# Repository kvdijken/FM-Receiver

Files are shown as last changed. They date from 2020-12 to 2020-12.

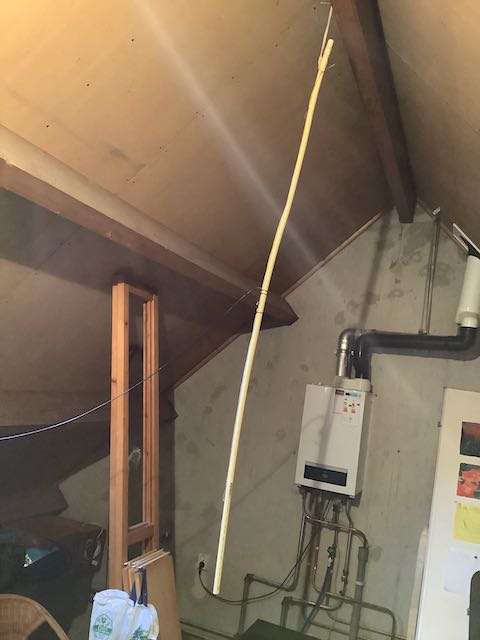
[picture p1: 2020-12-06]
photos/dipole antenna.jpeg

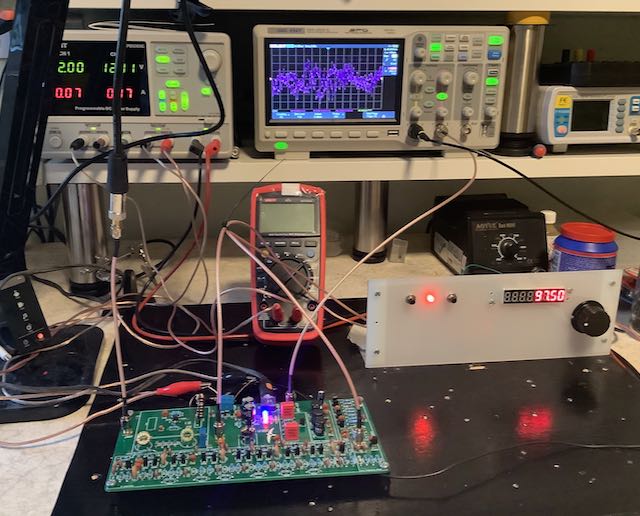
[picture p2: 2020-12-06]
photos/receiver.jpeg

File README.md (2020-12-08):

# FM Receiver

In this project you will find my home built FM receiver. The goal is to create a receiver with discrete components only, no integrated circuits. It delivers line level audio. It only needs an additional audio amplifier to be able to hear your favorite radio station from the speakers.

Performance is very good. I receive all FM radio stations with great clarity. Its sensitivity is 11𝜇V.

It lets you dial into preprogrammed radio stations, or to select frequencies yourself. Also you can change some internal receiver parameters such as intermediate frequencies and lowside/highside injection. 

The user interface runs on an Arduino Nano 328P. The receiver itself is built off discrete parts, no integrated parts are used.

In this project you will find
* Arduino source code of the digital section (in folder 'firmware/FM Radio 5.8')
* Kicad project with the schematic and pcb layout of the analog section (in folder 'hardware')
* documentation (in folder 'documentation')
* a Python project to model differential pair amplifiers (in folder 'IF Amplifier')
* some photos of my implementation
* measurements I have done on this receiver (in folder 'measurements').

In this project you will not find the schematic for the digital section yet. I will still have to create this schematic. The digital section is not complicated however. It consists of an Arduino Nano, three pushbuttons, one LED, 1 rotary encoder, one display and one Adafruit Si5351 breakout board. From the Arduino sourcecode you should be able to discover the wiring. The Si5351 delivers the two local oscillator frequencies which are needed for the receiver.

Keep in mind that the schematic, and the pcb which is derived from the schematic contain an serious error. I kept this error in the schematic, to keep the schematic and pcb design in sync. The error is described in the documentation. Also is described how to work around the error, which is quite simple. You can still use the pcb design, even with this bug. In the next version of this receiver this error will be solved.

In the next few weeks, months, my main focus will be on measurements on the receiver. I will try to characterise the receiver as well as possible. From there the receiver can be improved.

On Youtube you can find a demonstration of this receiver: https://youtu.be/TlIiLwKdwg0

Current version is 1.0

Feel free to ask/contribute.

> Written with [StackEdit](https://stackedit.io/).

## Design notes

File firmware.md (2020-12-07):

#FM Radio 5.8

To compile this Arduino sketch you will need the following libraries on your machine:

LedControl.h
from https://github.com/wayoda/LedControl or from the Library Manager in the Arduino IDE

si5351.h
from https://github.com/etherkit/Si5351Arduino or from the Library Manager in the Arduino IDE

Encoder.h
from https://github.com/PaulStoffregen/Encoder

Bounce2.h
can be installed from the  Library Manager in the Arduino IDE

> Written with [StackEdit](https://stackedit.io/).

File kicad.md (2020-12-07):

# Kicad project

For the Kicad project of th FM Receiver you will need the following:

* Digikey's Kicad symbol library, available from https://github.com/Digi-Key/digikey-kicad-library
* kvd footprint library, available in the `FM Receiver/kicad/kvd.pretty` folder

> Written with [StackEdit](https://stackedit.io/).

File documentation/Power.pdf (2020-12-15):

# Power

Measurements taken on version 1.0 of the receiver.

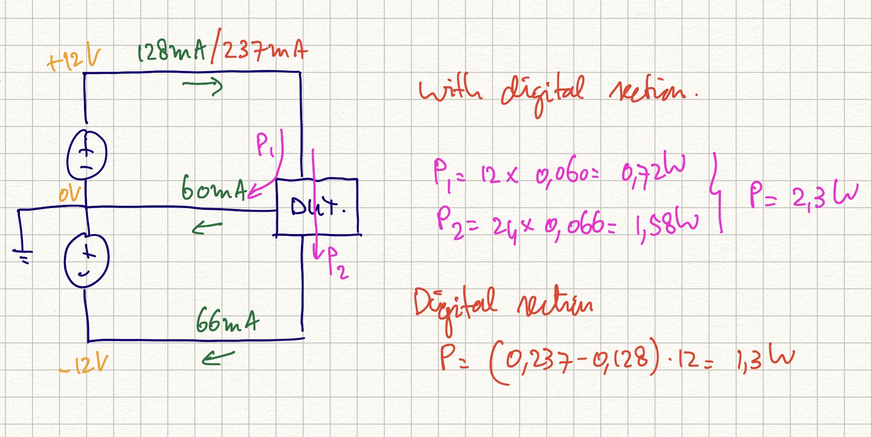
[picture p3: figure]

Power requirements:
- analog section 2.3 Watt
- digital section 1.3 Watt
| T (℃) | V (V) | R (Ω) | P (W)
R507 | 50 | 16.6 | 1100 | 0.25
R505 | 49 | 4.3 | 150 | 0.12
R103 | 36 | 7.8 | 560 | 0.11
R104 | 27 | 6.9 | 5100 | 0.01

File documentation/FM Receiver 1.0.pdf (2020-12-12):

# FM Receiver ver. 1.0

# A home built FM Receiver, ongoing project

K. van Dijken, december 2020
fm.homelab@gmail.com

## Introduction

A few years ago I started building some simple radio receivers. First these were AM receivers. Later my focus moved to FM receivers. Most of my knowledge of electronics and radio up to now has been gained from the internet. Very useful resources are the following
- Mateo Aboy videos on https://www.youtube.com/channel/UCfFq8r---cp2IBwoGcWWsvw, especially the videos by Dr. Christina Crespo.
- Electronics playlist of Caltech's Prof. Ali Hajimiri at https://www.youtube.com/playlist?list=PLc7Gz02Znph-c2-ssFpRrzYwbzplXfXUT (https://www.youtube.com/playlist?list=PLc7Gz02Znph-c2-ssFpRrzYwbzplXfXUT)
- RF Circuit Design - Bowick, 1982
- Experimental Methods in RF Design (Hayward, Campbell & Larkin)
- W2AEW's description of a pulse counting detector at https://www.youtube.com/watch?v=jQlN2fc7LJc

but also many more.

At this moment I have a very well
functioning FM receiver designed and built by myself. It receives all the public FM stations in my country with great clarity. It is a mono receiver. Although it can still be improved on many points I feel it is a good moment to publish it at this moment so others can benefit from it as well.

The current receiver is built on a PCB which I designed myself and was produced by JLCPCB. There is one major error in the design, but it is easy to solder your components around this design error. Also the current
implementation is a bit different from the PCB because during PCB production at JLCPCB I
discovered a very simple
improvement which is also
cheaper in components. The actual implementation can be built on the provided PCB.

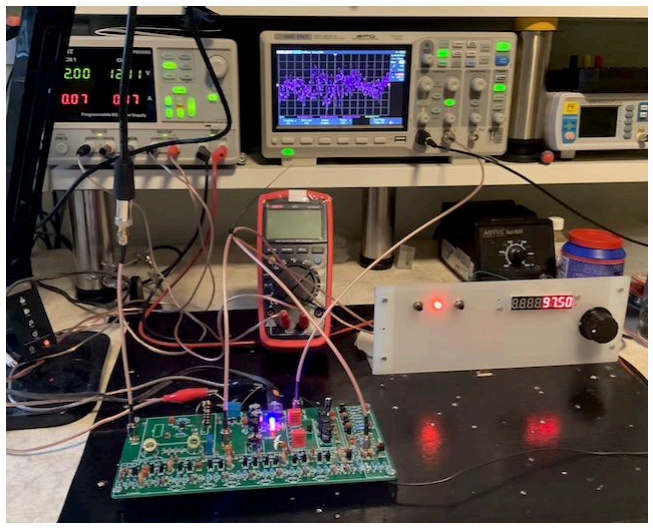
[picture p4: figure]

Complete receiver, with the digital section right at the back

The receiver has a large analog section and a small digital section. The digital section has the user interface with frequency/station selection, IF settings and some more features. The digital section is based on a Arduino Nano, with a Si5351 frequency synthesiser.

The project is an ongoing project. At this moment I am finishing performance measurements on the actual implementation. From the results of these, I will prepare for the next version of the receiver.

The analog section of the receiver runs on ±12 volts and consumes about 2.3 Watts. Sensitivity is about 50µV. The digital section burns 1.3 Watt when it is run from a 12V power source.

## Things to improve

Things I want to improve, in no particular order
- selectivity
- stereo reception
- less stages in the IF section (smaller values for R308, R314, R326 and R337 for higher current so larger amplification)
- remove the follower in the last stage of the IF amplifier.
- replace the RF mixer with a design which does not have toroids
- replace the RM pre-amplifier with a design without toroid
- signal strength indicator
- to program the digital section it needs to be disconnected from power, and needs to be connected to USB only. This is too cumbersome and should be changed.

## General architecture

The design is a commonly known heterodyne receiver, with two down-mixing stages:

1. RF Amplifier, one stage amplifier to boost the input signal, and isolate the antenna from the rest of the receiver.
2. RF Mixer, mixes RF down to the IF of 10.7 MHz (actually 10.66 MHz)
3. IF amplifier, for amplification and limiting of the signal at the intermediate frequency.
4. Low Frequency mixer, mixes the signal at 10.66 MHz down to the FM detection frequency of 450 MHz.
5. Pulse counting FM detector, converts the 450 kHz FM signal to audio
6. Audio section, filters out all frequencies higher than about 50kHz, and provides some amplification to line level audio.

## Antenna

The antenna which I have currently in use is a vertical dipole, with two 75 centimeter branches. It is located on my attic, which is about 10 meters above ground level. The antenna is connected through a 300 ohms coax to the receiver.


## RF Pre-amplifier

The RF pre-amplifier amplifies the input signal by about 10dB. Furthermore it tries to block signal coming in reverse direction from the receiver to the antenna based on its common base design.

Some time has been spent in trying to match the antenna impedance to the input impedance of the preamp. This did not result in much better reception however, so this has been abandoned for the moment. The antenna is directly connected to the emitter of the preamp's transistor Q201.

The current through Q201 (6mA) has been chosen such that its noise level is lowest.

The coil is chosen to perform in the RF domain. Number of windings are such that the coils impedance at 100MHz is reasonable (340Ω). The winding at which the signal is tapped has been found empirically .¹

C203 and C204 gave better performance in the receiver
when it was still in the experimental stage. On the PCB
however C203 and C204 do not seem necessary anymore.
Their locations are not populated. Also the impedance matching circuit at the input (L201 and C201) are not populated on the PCB.

## RF Mixer

The RF mixer is a double balanced diode ring mixer. The coils have been chosen to perform in the 100 MHz domain. They are trifilar wound.

The diodes are 1N6263 Schotky diodes. No effort has been made to match the diodes.

## IF Amplifier

The IF amplifier amplifies the 10.66 MHz signal. It starts with a common base amplifier to prevent reverse signals feeding back into the RF mixer. The CB stage has an input impedance of about 10Ω. Next is a series of differential pair amplifiers, with inbetween 10.7MHz Murata crystal filters. The differential pairs provide amplification, but also limiting, which is essential in FM receivers.

See the document "IF Diffpair" in this directory for a more detailed description of the diffpairs functioning. The folder /IF Amplifier/Diffpair4 contains a Python project to model the workings of a differential pair amplifier. The section "RF and IF measurements" in this document contains some result of some measurements done in the RF and IF amplifiers.

Halfway the IF amplifier there is a coil which inverts the phase of the signal. This has been done to prevent positive feedback from the output signal of the IF amplifier onto its input.

Because there is much about toroids which I do not understand at this moment, there is a lot of ¹ guessing in this part. For this reason I'd like to replace this design with a resistor based design. Up to now I have not been able to reasonable performance with resistors however.

Dipole antenna

Finally there is a follower. This follower is a left-over from a previous version of the receiver, in which the IF amplifier was followed by a low impedance low-frequency mixer. To prevent loading of the last IF stage the follower was introduced. With the easy to drive JFET mixer which is in use at the moment, the follower should not be necessary however.

## Low frequency mixer

The low frequency mixer is a very simple mixer which I have developed during the production of my video on JFET mixers https://www.youtube.com/watch?v=0p6FXlhfmts.

## Pulse Counting FM Detector

See the document "Pulse Counting FM Detector" in this same directory for a detailed description of the detector.

## Audio section

The audio section starts with a 100 kHz lowpass filter to filter out the 450 kHz remnants of the detector section. Then a simple common emitter amplifier to get signal level up to line level.

## PCB Design

- There is a design error at R304. R304 should not be connected to VEE, but to VCC.
- The PCB has 20x10 centimeters dimensions.
- In the high frequency sections (RF amplifier, RF mixer, IF amplifier and FM detector) the ground plane has only been implemented on the bottom side, not on the top side of the PCB. This was done to minimise stray capacitance.

## Differences between PCB design and current implementation

At the following points the current implementation differs from the schematic. In the next revision of the schematic and PCB this will be changed.

1. In the circuit diagram C505 is a 470pF capacitor, this is an error. It should be 220pF. In the actual implementation it is an 220pF capacitor.
2. In the circuit diagram one side of R304 is connected to VEE. This is an error. It should be connected to VCC. The PCB also has this error. In the actual implementation it is connected to VCC. On this photo the bodge is visible.
3. In the actual implementation L506 is 1mH instead of 1.2mH as is given in the circuit diagram. This is because I did not have a 1.2mH at the moment.
4. I used a 9.1kΩ value for R303 instead of 9.2kΩ.
5. I used a 1kΩ resistor for R308 instead of a 4.7kΩ.
6. The input impedance matching network on Q201 is not implemented at all. C201 is shorted, and L201 is left blank.

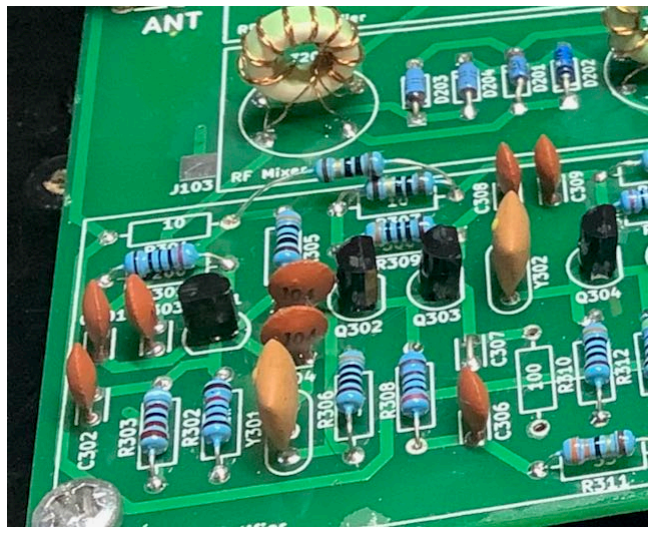
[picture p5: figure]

7. D103 is a red led, D104 is a blue led. To limit the current (and so brightness of D104) R104 is 5.1kΩ instead of 560Ω.
8. Resistors R310, R316, R322, R328, R334, R340 and R346 are not implemented. Also capacitors C307, C311, C315, C319, C323, C327 and C331 are not implemented, but shorted. The base of the righthand transistors of the differential pairs can be connected to ground directly.
9. The sixth order lowpass filter at the input of the detector has been replaced by a 4th order filter. C503 is left open, L503 has been shorted. L501, L502, C501 and C502 have the values as mentioned in the schematic.

## RF and IF measurements

In the following figure you can see measurement of the signal strength at various places in the RF and IF amplifier for different radio stations. The limiting action at about 10dBm is very obvious.

R304 bodge

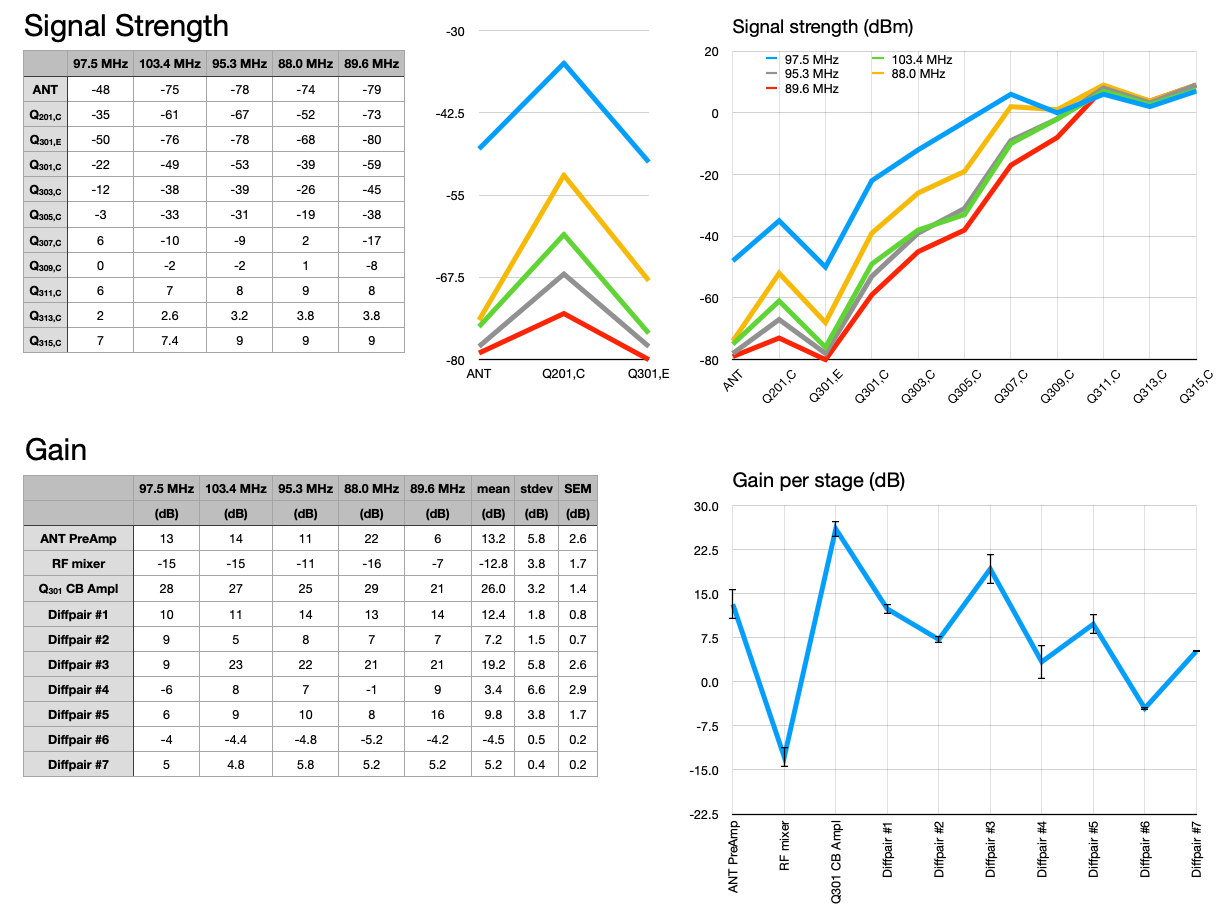
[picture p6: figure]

## Digital section

The digital section handles station selection, frequencies and signal level for the local oscillators and whether to have low-side or high-side injection for the RF section. The firmware runs on an Arduino Nano 328P. The Arduino instructs the Si5351 which generates the local oscillators for the RF and low frequency mixers. Source code for the firmware running on the Arduino is in the folder /firmware.

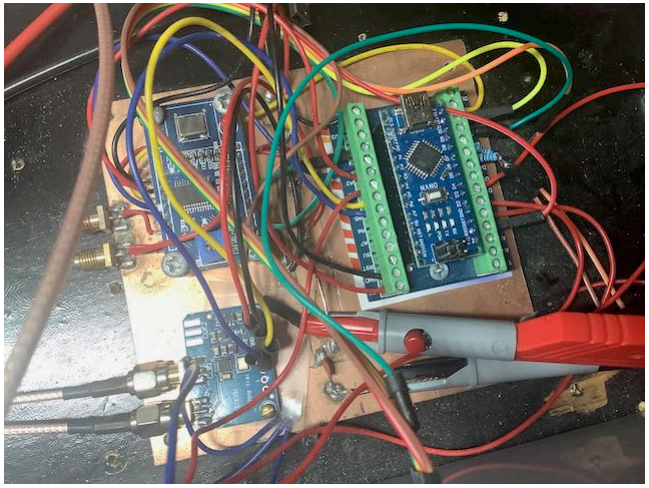
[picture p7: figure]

Digital section. In the topleft is a AD9851 which is not used in this project.

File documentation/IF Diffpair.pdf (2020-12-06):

# Measurements and modeling of a BJT differential pair in IF

amplifier of FM receiver.

## BJT, #diffpair, #differential pair, #python, #fsolve, #IF Amplifier, #FM Receiver

Koen van Dijken, November 2020.

BJT differential pair amplifiers provide a well defined amplification, as well as a nice limiting action. Both of these are very useful in the IF amplifier for an FM receiver.

In the IF amplifier of my homebrew FM Receiver there is a chain of differential pairs. I did detailed scoping in one of these pairs, and found that the shared emitter voltage is not completely stable. At first this surprised me. To completely understand this I described the circuit's behaviour in a few expressions, and coded these expressions in a small Python script. With the output of the script it is easy to show the amplification of the differential pair, but also the limiting action and the unexpected voltage fluctuations on the shared emitter.

I will show the script, the scripts output, and finally I will also give an intuitive explanation of what's going on in the diffpair.

To show you the context of the diffpair, this is part of the IF amplifier.

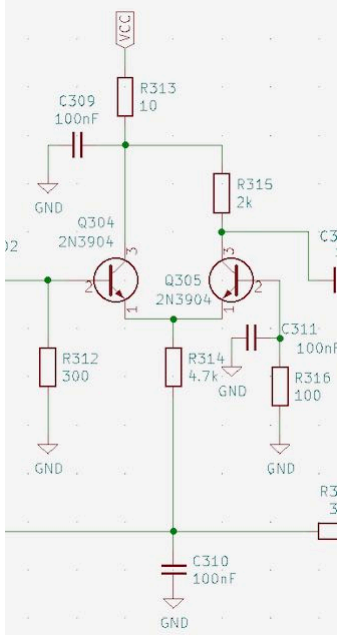
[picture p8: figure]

As a sidenote, since I created this circuit diagram, the actual implementation has changed somewhat. The base of the second transistor, which in this diagram is Q305 is tied to ground directly. There is no need to use R316 and C311. For the story which follows, it is not important.

What I saw at the shared emitter is this:

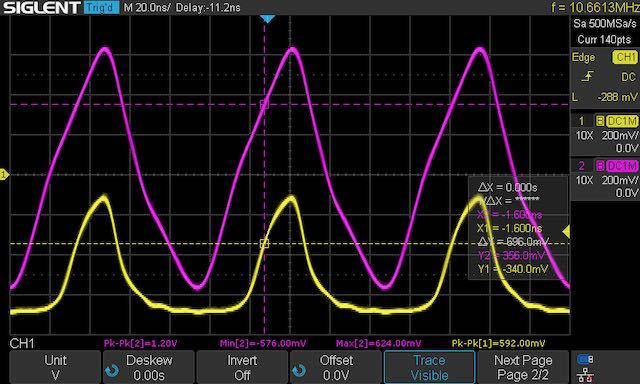
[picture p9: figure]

In purple you see the input voltage at the base of Q304, in yellow the shared emitter voltage at its emitter. What surprised me at first is that the emitter voltage is not constant, and not by a small amount. It rises with the input voltage, but only when the input voltage is positive. For negative input voltages, the emitter voltage is constant.

To understand this I modeled the diffpair as such:

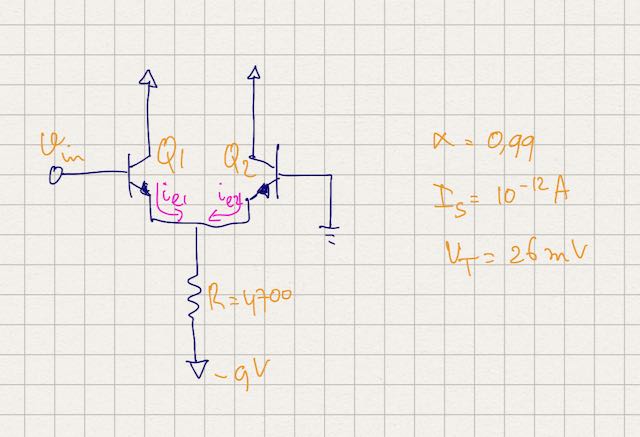
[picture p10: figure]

The model only consists of the two transistors, a common tail resistor, the input signal at the base of Q1. The base of Q2 is tied to ground, and both collectors are put connected to the positive voltage supply. The actual voltage of the positive supply is not important as the current is dictated by both transistors.

The model can de described by the following equations:

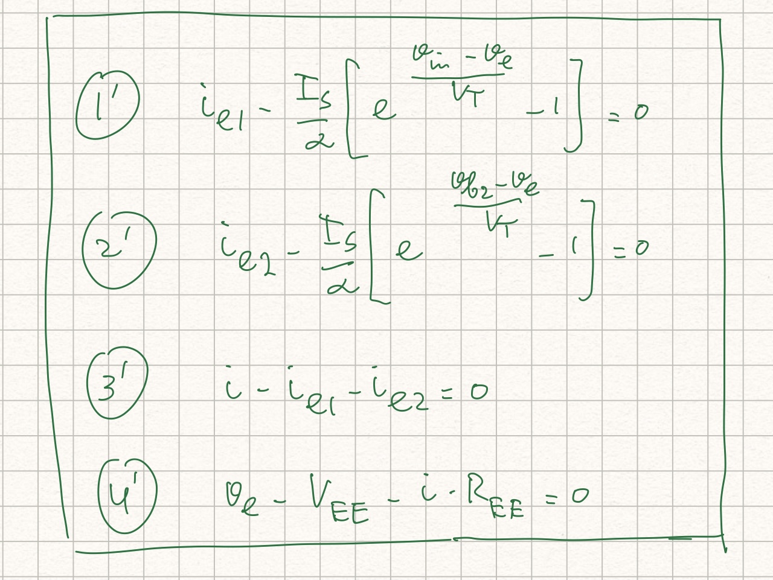
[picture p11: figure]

Equations 1 and 2 are the Shockley diode equations, extended with the transistor amplification. Equation 3 is the Kirchhoff current law at the shared emitter node. Equation 4 is Ohm's law over the tail resistor.

ie1 is the current through the input transistor Q1 and ie2 is the current through the output transistor Q2.

These equations form a nonlinear set of equations which cannot be solved algebraically. With Python's scipy.optimize.fsolve function approximated solutions for these equations can be found quite easily. I wrote a script to find solutions for these equations and plot these solutions for varying input voltages.

The output of the script are these two plots:

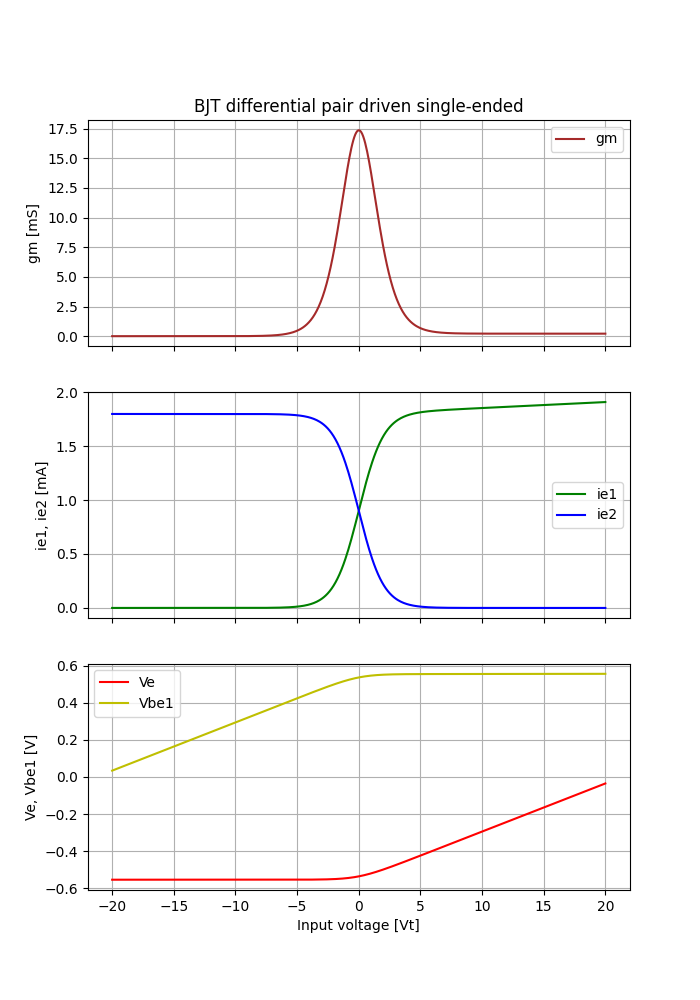
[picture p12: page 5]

The middle plot shows the currents through the transistors. The bottom plot shows the shared emitter voltage Ve in red, and the base-emitter voltage drop Vbe1 for the first transistor in yellow. The top plot shows the transconductance as calculated from the middle plot. This is essentially the slope of ie2 in the middle plot. Note that the x-axis is in units of 26 millivolts, the thermal voltage.

Several observations can be made from these plots.

1. Within an input range of +/- 2 times the thermal voltage, current through the output transistor depends linearly on the input voltage. The diffpair makes a good amplifier within this input range.
2. Above about 3 times the thermal voltage, the output current starts to level off. This is the before-mentioned limiting action. For input signals larger than about 5 times the thermal voltage, output current does not increase anymore.
3. For large positive input voltages, the shared emitter voltage raises linearly with the input voltage.
4. The emitter voltage remains constant for negative input voltages.
5. The base-emitter voltage drop for Q1 is nearly 0.6 volts for positive input voltages.
6. The small signal gain gm nicely follows gm = I / 2VT (blue dot in top plot), where I is the total tail current.

Observations 3 and 4 explain the signals seen before in the oscilloscope plot. For positive input signals, the emitter voltage follows the input voltage, being a diode drop lower. For negative input voltages the emitter voltage remains constant for all input voltages less than zero.

The base-emitter voltage drop of nearly 0.6 volts is nearly completely dictated by the reverse saturation current IS. I did some simple measurements on a 2N3904 to determine the reverse saturation current. It turned out to be about 1pA. This value of 1pA was used in the Python script.

These are my notes for the measurement of the reverse saturation current:

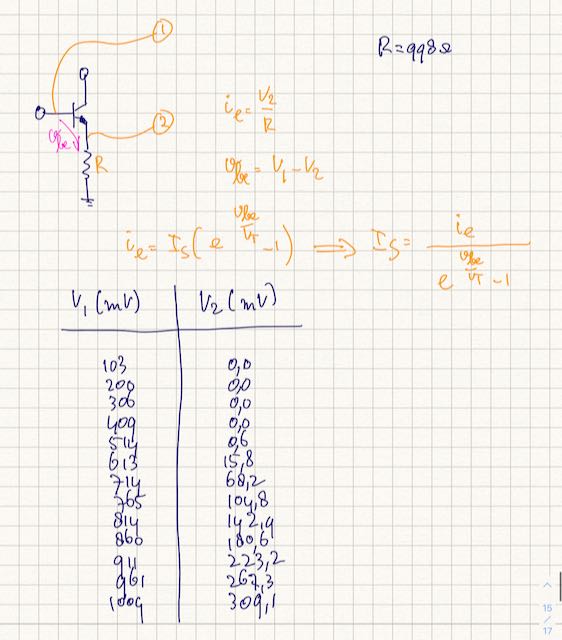
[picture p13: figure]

Note that in these formules the α factor is missing. But this is not important, as it is close to one, and the measurements are not very accurate anyway. The measurements were taken with two multimeters. The measured values for V1 and V2 are entered into this sheet to calculate the reverse saturation current IS:

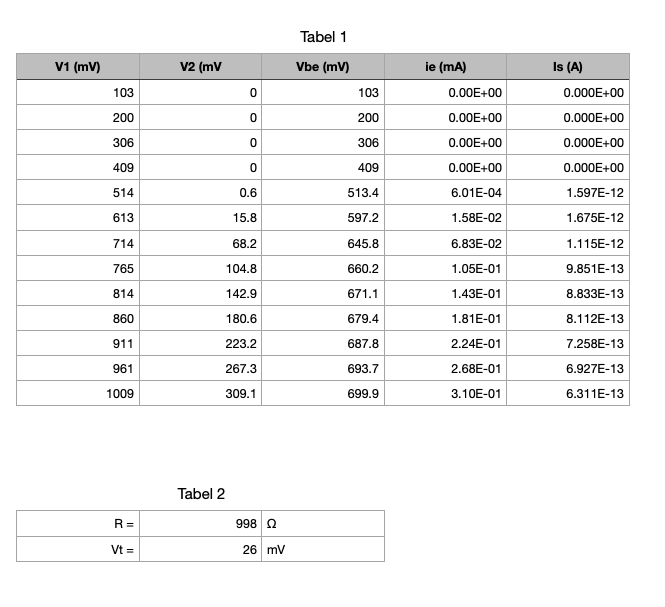
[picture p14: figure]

Apart from the zero values for IS, the calculated values hover around 1pA.

The behaviour of the emitter voltage can also be explained intuitively quite easily. Below a certain negative input voltage, Q1 gets into cutoff. It is not able to regulate the voltage at the shared emitter anymore. The emitter voltage is completely dictated by Q2. As the base of Q2 is tied to ground, there is nothing to let the emitter fluctuate, and as such it will remain constant at about a diode drop below the base of Q2. For positive input voltages, Q1 will be in its active region. When the input voltage rises above a certain level, it will cause Q2 to get into cutoff as Q1 will conduct all the current. The shared emitter voltage is dictated by Q1. At this moment we have a simple emitter follower circuit. The emitter voltage will follow the input voltage minus one diode drop.

To get the story complete, I changed the Python script somewhat to model the circuit when it is driven differentially. That is, the base of Q2 gets the same input voltage as Q1, but opposite in phase. This is the output of the script. Compare it with the output of the script when it is driven non-differentially, only on Q1. I leave it as an exercise to understand the difference between the two.

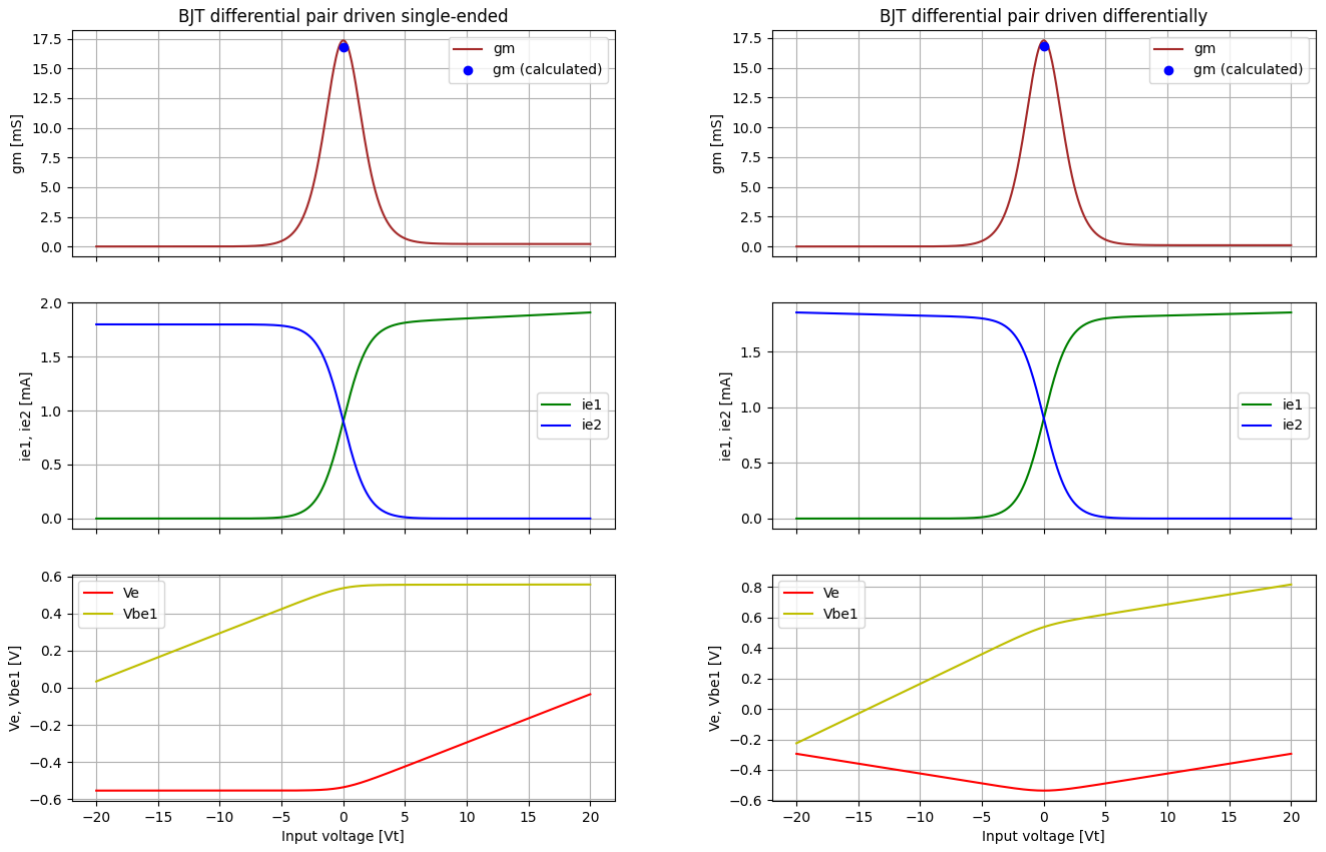
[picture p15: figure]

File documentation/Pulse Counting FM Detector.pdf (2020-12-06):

FM Detector | 2
1. Lowpass input filter | 3
2. Buffer (Q2) | 4
4. Pulse train generator (Q3, Q4, Q5) | 4
5. Buffer (Q6) | 8
6. Lowpass filter (L4, C6, L3, C11,L6, C15) | 10
7. Line level amplifier Q14 | 12

## FM Detector

The FM detector (demodulator) demodulates the 450kHz FM signal into line level audio. The 450kHz signal is at the second intermediate frequency. The FM detector is implemented as a pulse train generator followed by a low pass filter (sometimes called a pulse count detector).

The FM detector consists of several stages:

1. A 4th order 750kHz lowpass filter to filter out all mixing products except the 450kHz intermediate frequency (L8, L9, C3, C1).
2. A buffer (Q2), to provide a constant load impedance for the preceding filter.
3. Pulse train generator (Q3, Q4, Q5), which generates a constant width down-pulse for every upward slope of the input signal. With the changing frequency of the carrier, the duty cycle of the resulting pulse train varies in accordance to the carrier frequency.
4. Buffer (Q6)
5. 6th order 100kHz lowpass filter (L3, L4, L6, C6, C7, C11) filters the pulse train with its changing duty cycle into audio and FM subcarrier signals.
6. A final amplifier Q14 to amplify the signal to line level.

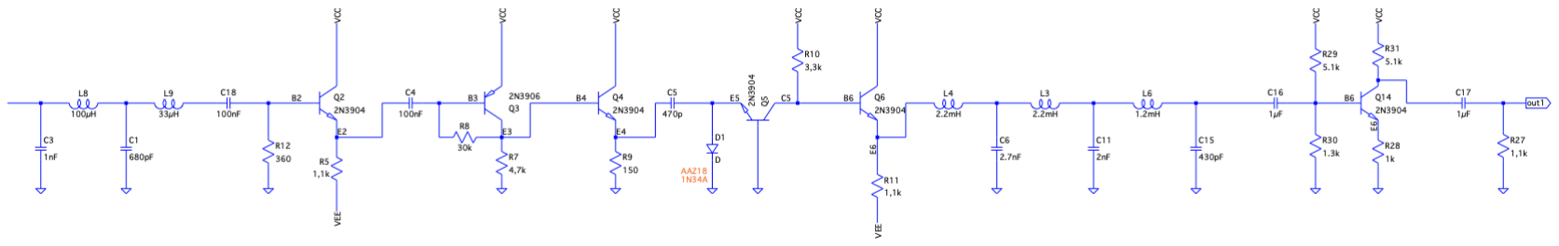
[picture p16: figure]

### 1. Lowpass input filter

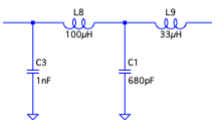
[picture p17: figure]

A 4th order 750kHz lowpass filter to filter out all mixing products except the 450kHz intermediate frequency (L8, L9, C3, C1). Input impedance is 2kΩ, output impedance is 300Ω.

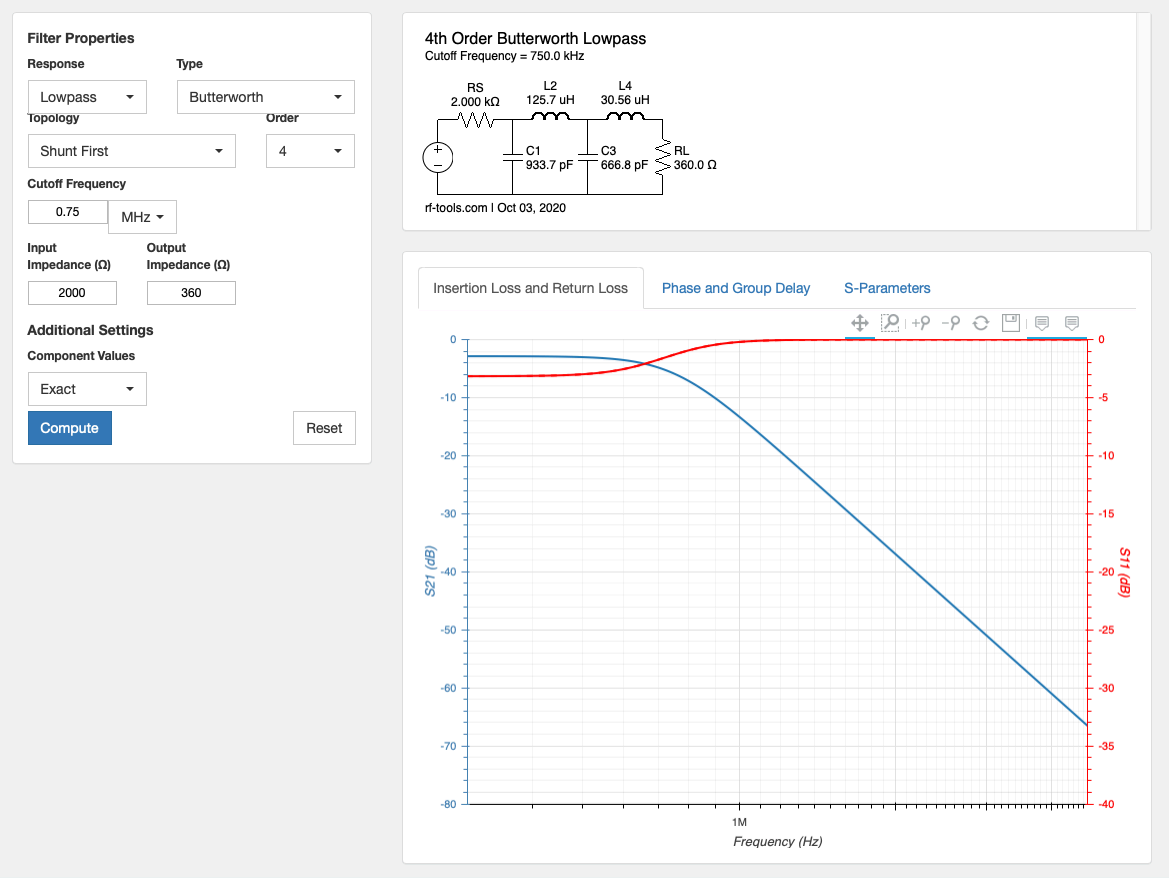
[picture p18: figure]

### 2. Buffer (Q2)

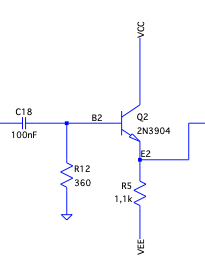
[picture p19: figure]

Input impedance is 360Ω. This buffer provides a frequency independent 360Ω load for the preceding filter.

### 4. Pulse train generator (Q3, Q4, Q5)

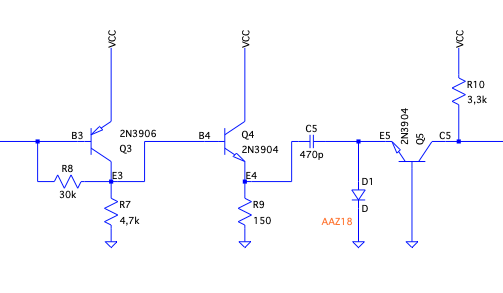
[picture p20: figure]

Q3 provides basic amplification, Q4 is a follower and Q5 is the actual pulse train generator.

The pulse train generator generates a fixed width, down-pulse at every rising edge of the input signal. On the output is a pulse train with a duty cycle which is related to the frequency of the input signal. With an FM modulated carrier on the input, the duty cycle directly relates to the instantaneous carrier frequency. After a lowpass filter on the output (ie. taking the average), a voltage results which relates to the instantaneous carrier frequency. Because of this this voltage is directly related to the (audio) signal which was used to modulate the carrier. Net result is demodulation of the FM modulated carrier into the modulating (audio) signal.

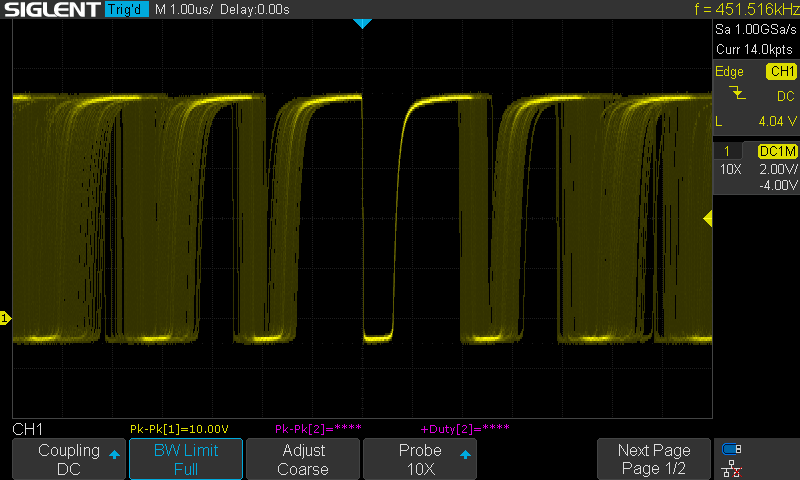
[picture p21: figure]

Q3 provides as much amplification as possible, to drive the circuit C5-D1 as hard as possible. It utilises a collector feedback biasing scheme. It has a small amount of negative feedback.

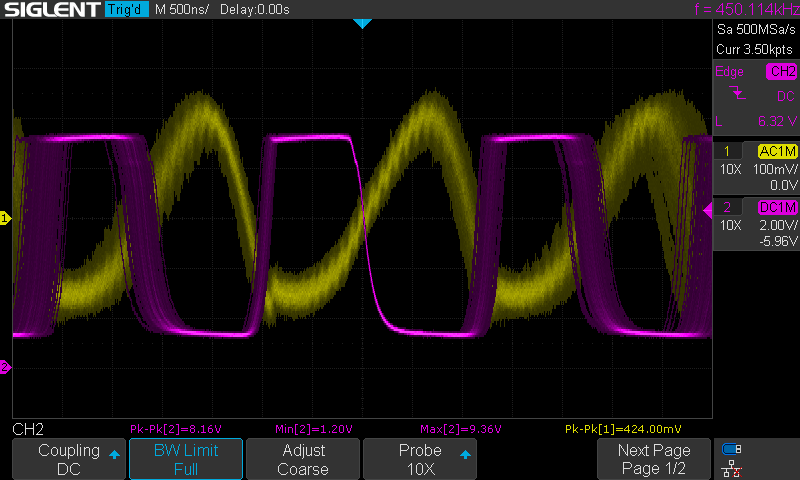
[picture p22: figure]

The Q3 amplifier is implemented as PNP amplifier. This produces an output signal (at E3) with a longer low period than a NPN amplifier. The longer low period allows for more choice for C5, which is important for the duration of the output pulse. Q3 needs to be followed by a buffer. Direct loading it with C5-D1 would load it too much.

Q5 is driven over the C5-D1 circuit. The maximal voltage on Ve5 is equal to the diode drop of D1 (level 1). At that moment the diode starts to conduct and Ve5 cannot rise any higher. Minimal voltage on Ve5 is about -0.6V because of the base-emitter voltage drop Vbe of Q5 (level2). With Ve5 at -0.6V Q5 starts conducting, which causes the collector voltage of Q5 to drop. R10 should be chosen such that it drives Q5 into saturation. When Ve5 is higher than -Vbe, Q5 is in cutoff, and Vc5 is equal to Vcc.

Q4 drives down its emitter voltage hard (moment A). This will drive the emitter voltage of Q5 (Ve5) down as well, until it reaches its minimal voltage at the diode drop Vbe of Q5 (moment B, level 2). At that moment Q5 starts to conduct and discharges C5. Because Ve5 is negative D1 does not conduct; the current through Q5 only feeds the discharge of C5. The rate at which C5 discharge is determined by the RC constant of R10 and C5. Discharging C5 will increase the voltage at E5 Ve5.

SIGNAL ON COLLECTOR OF Q5. IT SHOWS THE FREQUENCY-INDEPENDENT PULSE WIDTH.

IN- AND OUTPUT OF Q3. YELLOW = VB3, PINK = VC3.

At moment C the capacitor C5 is discharged to such a level that Ve5 is less than the diode drop of the base-emitter junction fo Q5, Q5 stops conducting, which causes the voltage at its collector to rise to Vcc. Voltage at E5 Ve5 will remain constant because Ve4 remains constant until moment D, and neither Q5, nor D1 conduct until then.

At moment D Ve4 rises again which will drag Ve5 with it (neither Q5 nor D1 conduct), until Ve5 reaches the forward voltage of D1 (at moment E) and will remain at that voltage until the next cycle. This causes C5 to charge again.

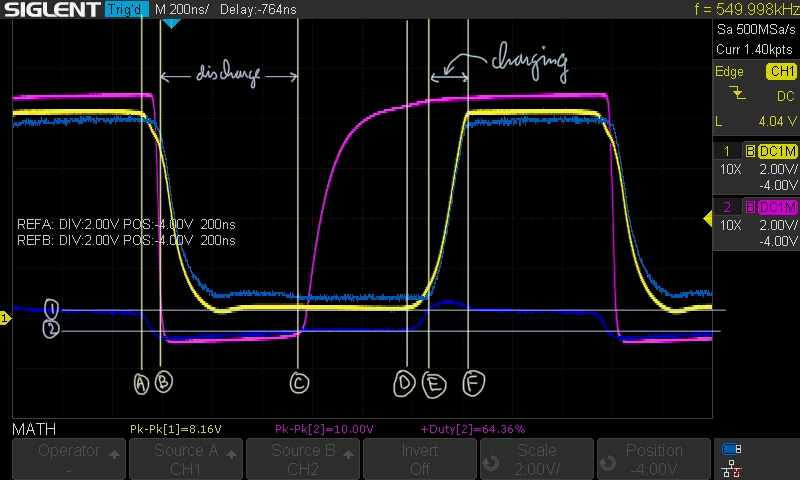
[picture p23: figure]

We choose R10 such that Q5 is in saturation when Q5 is conducting. Then we choose C5 such that the the discharging time of C5 is less than the time which Ve4 is low.

The switching on-off of the current through Q5 causes Vc5 to switch between the saturation voltage (VC5≈0V, current > 0) and Vcc (current = 0). The rate at which Vc5 rises from the saturation voltage to Vcc is determined by the RC constant of R10 and the parasitic capacitance Ccb of Q5. The charging of Ccb is shown by the slope of the pink line between moments C and D in the above figure.

D1 is chosen to have a low voltage drop. By having a low voltage drop it demands less of preceding amplification stages. To have steep edges on Vc5 we need a voltage as square as possible on Ve5. The falling edge on Ve5 should be steep to get deep and steep pulses on Vc5.

STAGES IN THE PULSE TRAIN GENERATOR. YELLOW: VE4
DARK BLUE: VE5
LIGHT BLUE: VOLTAGE OVER C5
PINK: VC5
VE4 VE5 VCAP VC5

DETERMINATION OF R10 AND C5

Values of R10 and C5 have been determined experimentally . First R10 is chosen to get Q5 into ¹ saturation. The FM signal is modulated around the IF2, with a frequency deviation of ±75kHz.

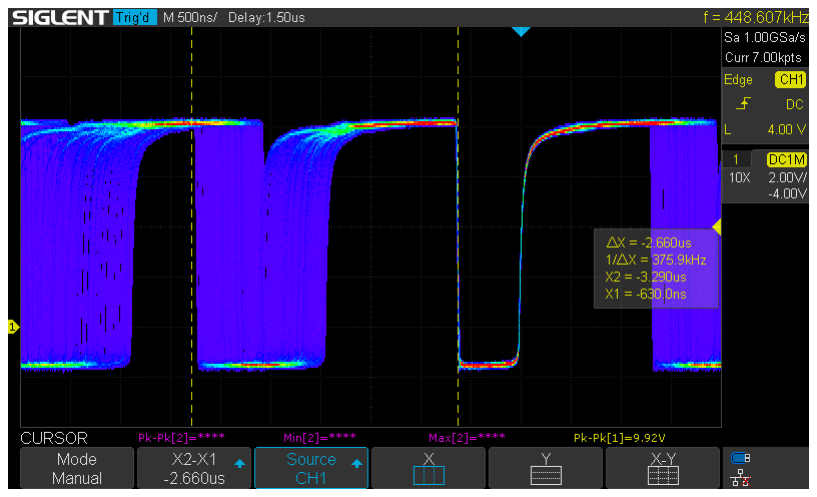
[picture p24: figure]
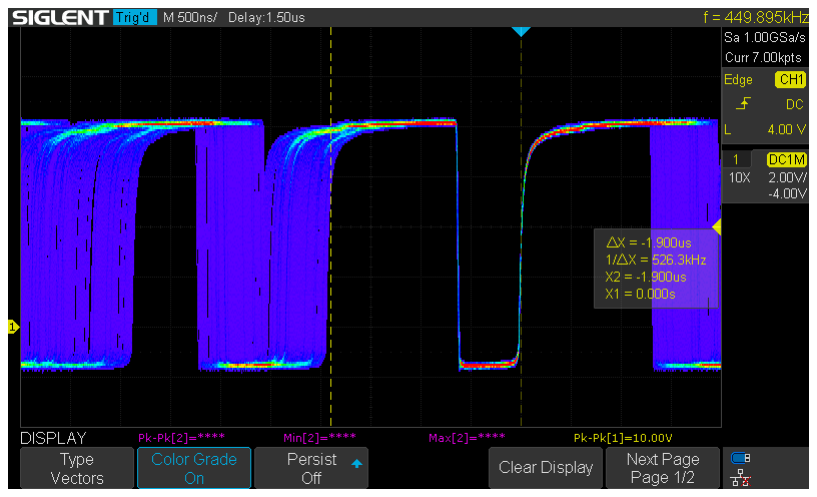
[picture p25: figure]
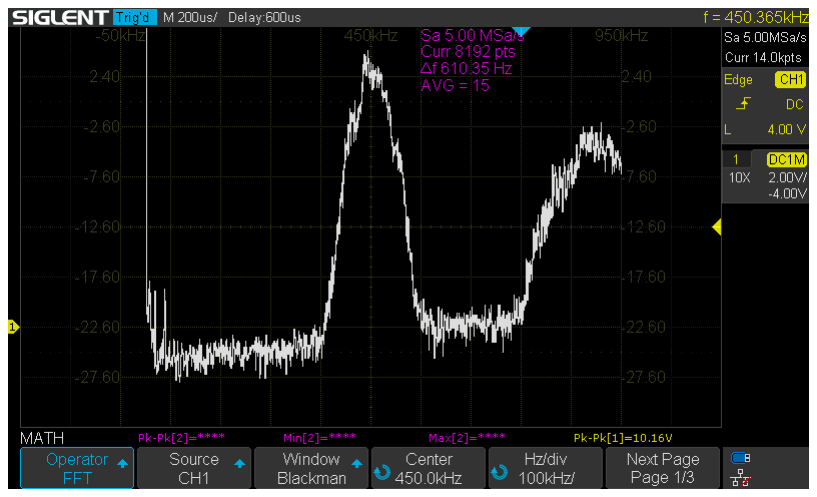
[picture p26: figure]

SIGNAL AT C5 SHOWING MAXIMUM FM FREQUENCY DEVIATION OF ±75KHZ AROUND THE SECOND INTERMEDIATE FREQUENCY OF 450KHZ.

Largest audio signal is obtained when the low pulse width on C5 is [fIF2]⁻¹ / 2 ≈ 1μs. To account for variation in Q5's β, and to allow Q5's parasitic capacitance to charge through R10 it is better to make the pulse width on C5 somewhat smaller. Larger capacitance C5 gives a longer low pulse on C5.

The next two figures show that the pulse width on C5 (pink) is independent of the frequency of the input signal (yellow is the signal on E4).

It should be possible to calculate these as well. The discharge time of C5 can be calculated with 1

t = Qc / Ic = Vc * CC4 * R10 / VR10

where

Qc = charge on C5
Ic = Q5 collector current
Vc = maximum voltage over C5 (=Ve4-Ve5, ∼7V) CC5 = C5 capacity (421pF)
R10 = 3275Ω
VR10 = maximum voltage over R10 (9.92V)

This gives t ≈ 0,95μs, which is 170% of the measured value.


The following figure shows the signal on E5 in pink. The upper and lower voltages represent the D1 diode drop (about 260mV), and the Vbe of Q5 (about 480mV). In yellow the signal on E4.


### 5. Buffer (Q6)


To prevent loading of Q5 it is followed by a high impedance follower Q6.

### 6. Lowpass filter (L4, C6, L3, C11,L6, C15)


LC filters need a constant load impedance to have a flat frequency response in the passband. For this reason it is followed by a class A 1kΩ input impedance amplifier. The next stage in the lab test setup is a Behringer Xenyx 802 audio mixer which does not have a constant input impedance, see next figure.


Actual implementation of the LC lowpass filter (including emitter follower), input AC-coupled with a 47μF capacitor:

INPUT IMPEDANCE OF BEHRINGER XENYX 802 AUDIO MIXER


### 7. Line level amplifier Q14


This amplifier amplifies the audio and FM subcarrier signals to line level. It also provides a constant 1kΩ resistive load for the preceding filter. This amplifier is the last stage in (the current) setup. Next stage is a Behringer Xenyx 802 audio mixer. A stereo decoder can also be implemented after this stage. The output level seems to be right over the entire FM 75kHz bandwidth.

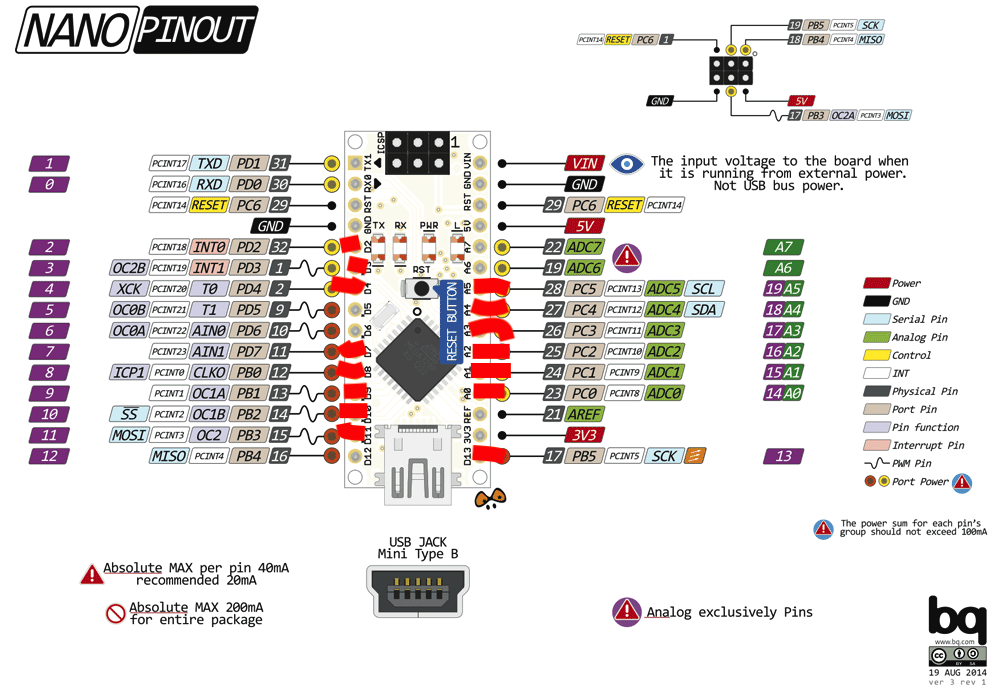
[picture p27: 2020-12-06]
firmware/FM Radio 5.8/Arduino-Nano-Pinout.png

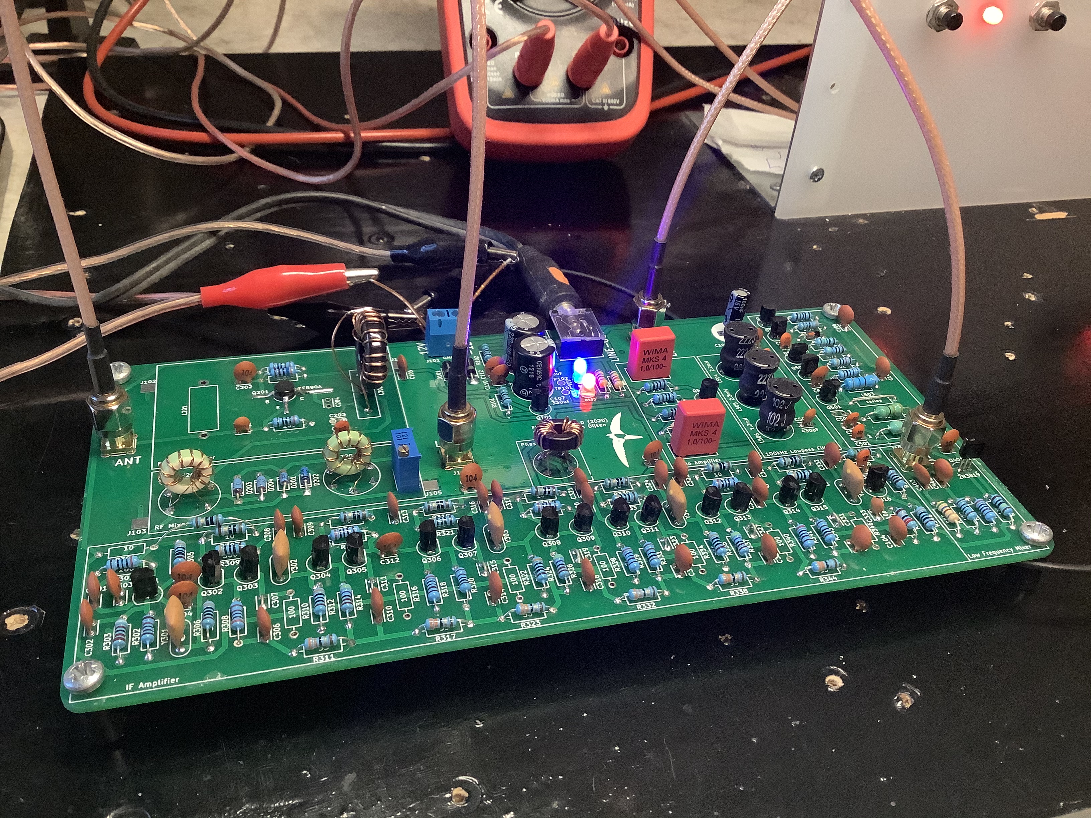
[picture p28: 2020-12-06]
photos/analog pcb.jpeg

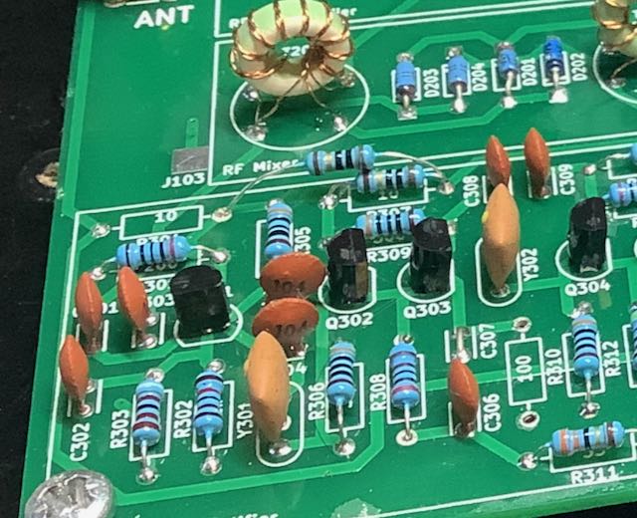
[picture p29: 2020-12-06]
photos/R304 bodge.jpeg

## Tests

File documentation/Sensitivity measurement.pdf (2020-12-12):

# Sensitivity measurement

Sensitivity measurements are done on the version 1.0 of the FM receiver. They are done using a Siglent SDS1202X-E oscilloscope. Wherever possible the 10x probe was used. When the signal was too small, the 1x probe was used.
Sensitivity is the lowest signal at the antenna which can still be detected and decoded into audio.
Sensitivity is calculated by finding the smallest signal at the antenna which produces an audible signal at the output. 'Audible' is somewhat subjective.
The ITU Radiocommunication Assembly mentions "that the sensitivity of a receiver is a measure of its ability to receive weak signals and to produce an output having a usable level and acceptable quality" . ¹
This is also fairly subjective.
In the FM receiver under test, I tested the station with the weakest signal which can be received in my neighbourhood. This is at a frequency of 88.0 MHz . It is received with great clarity. There may be weaker signals, but selectivity also plays a role to receive weak signals if they are close to stations with stronger signals.
To test if the signal at which it enters the receiver is the weakest signal the receiver can detect and decode, a 50Ω 20dB resistive attenuator is inserted between the antenna and the receiver. Even with this 20dB attenuator the station is received. Audio quality is not great anymore, but can still be listened to with great ease. Because the definition of sensitivity is fairly weak, I define the signal of the station at 88.0 MHz with the 20dB attenuator as the smallest signal the receiver can detect and decode.
The measurement is taken as part of the characterisation of the IF amplifier. For the station at 88.0 MHz (with attenuator) the signal at the collector of Q315 is at the limiting level 8dBm. The signal level at the antenna entrance is -113dBm. It must be noted that signal levels this low are at the limit of what I can measure with my equipment. The signal nearly disappears in the noise of my oscilloscope.
-113dBm (50Ω) is equal 50µV.
The sensitivity of the FM receiver version 1.0 is 50µV.

R-REC-SM.1840-0-200712, in https://www.itu.int/dms_pubrec/itu-r/rec/sm/R-REC- ¹ SM.1840-0-200712-I!!PDF-E.pdf (https://www.itu.int/dms_pubrec/itu-r/rec/sm/R-REC-SM.1840-0-200712-I!!PDF-E.pdf)

# Signal Strength (dBm)

| 97.5 MHz | 103.4 MHz | 95.3 MHz | 88.0 MHz | 88.0 MHz (att.) | 89.6 MHz
ANT | -48 | -75 | -78 | -74 | -113 | -79
Q201,C | -35 | -61 | -67 | -52 | -108 | -73
Q301,E | -50 | -76 | -78 | -68 | | -80
Q301,C | -22 | -49 | -53 | -39 | -66 | -59
Q303,C | -12 | -38 | -39 | -26 | -61 | -45
Q305,C | -3 | -33 | -31 | -19 | -61 | -38
Q307,C | 6 | -10 | -9 | 2 | -57 | -17
Q309,C | 0 | -2 | -2 | 1 | -51 | -8
Q311,C | 6 | 7 | 8 | 9 | -28 | 8
Q313,C | 2 | 2.6 | 3.2 | 3.8 | -18 | 3.8
Q315,C | 7 | 7.4 | 9 | 9 | 7.6 | 9

### Signal strength (dBm)

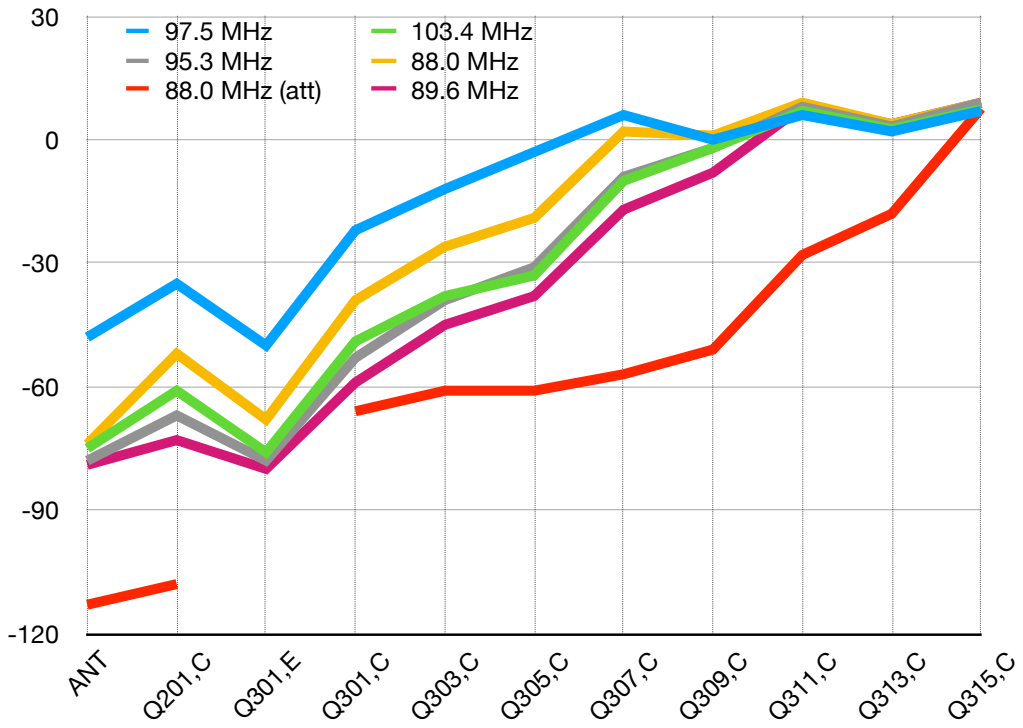
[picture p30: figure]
ANT; 97.5 MHz; 103.4 MHz; 95.3 MHz; 88.0 MHz; 88.0 MHz (att); 89.6 MHz

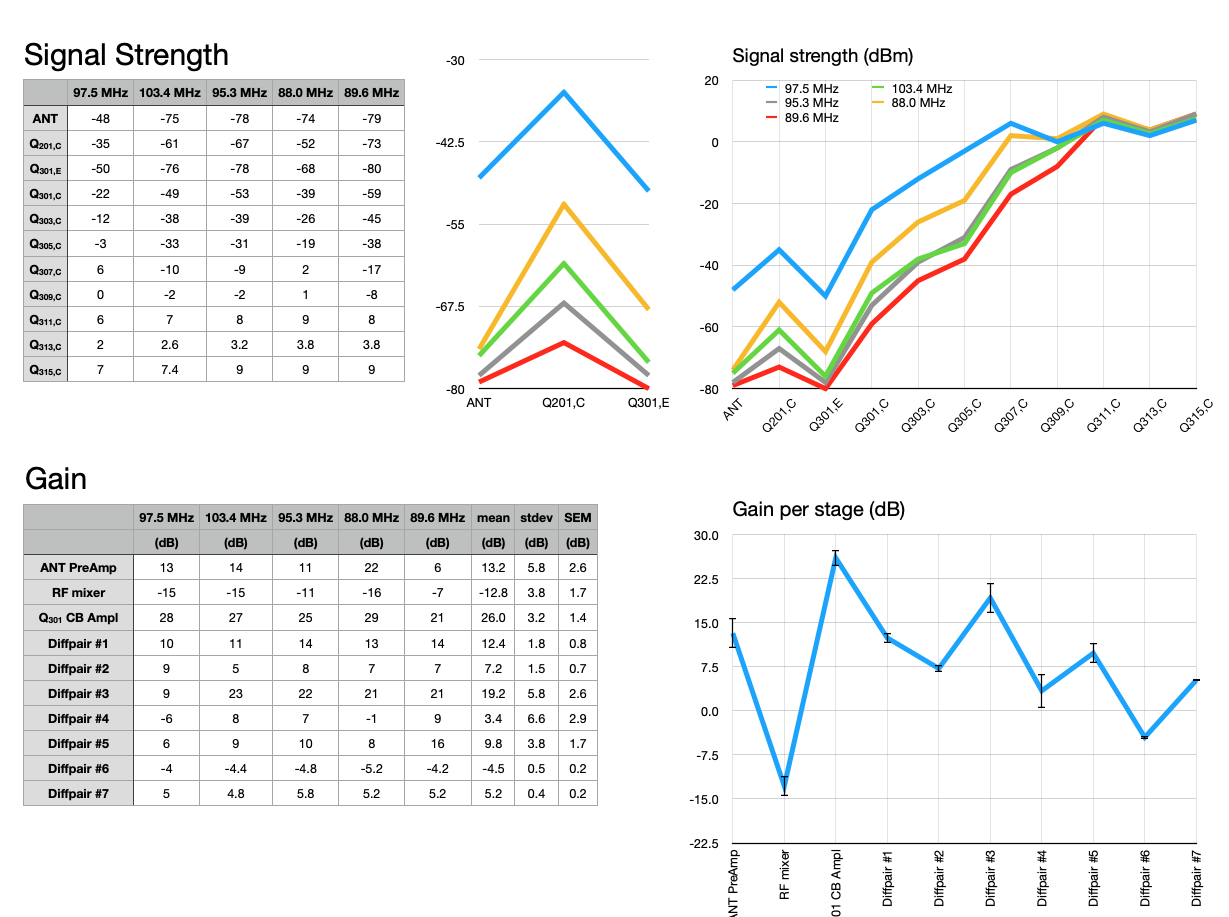
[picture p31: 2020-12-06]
measurements/Gain in the IF stages.png

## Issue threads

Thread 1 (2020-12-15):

Q101 and Q102 are undersized

kvdijken, 2020-12-15:
I blew Q101 by temporarily connecting a large capacitor across C101. Charging this capacitor created an extra surge current so that Q101's maximum collector current of 200mA was exceeded (see 2N3904 datasheet). Normal current through Q101 is about 130mA. A beefier Q101 should provide some more headspace.

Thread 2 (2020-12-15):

Describe a suitable power supply

kvdijken, 2020-12-15:
The design needs a negative and positive power supply of 12 volts. Currently is has been run from a lab power supply (type Siglent SPD3303C). Also the performance measurements thus far have been done running from this lab power supply.

Experiments with a cheap Hyland split rail power supply (https://www.aliexpress.com/item/4000148469416.html) which is based on a XLSEMI XL6008 shows a dramatic decrease in performance of the receiver. On the power rails of the receiver a large 430 kHz switching noise is seen.

Also powering the digital part of the receiver directly from the 12 volt of the analog part leaves much digital noise on the analog part, with some decrease in performance. Powering the digital section from the 5 volt of the lab power supply leaves very clean power rails on the analog part.

The power supply of the receiver should be an integral part. It should be able to be fed from either mains power (110/220 volts), or a 12-24 volts switching power supply. Power rails in the analog part should be clean.

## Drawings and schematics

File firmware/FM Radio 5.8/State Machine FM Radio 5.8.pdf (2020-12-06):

aantreffen'TÉIEÉ prostation | meetstations

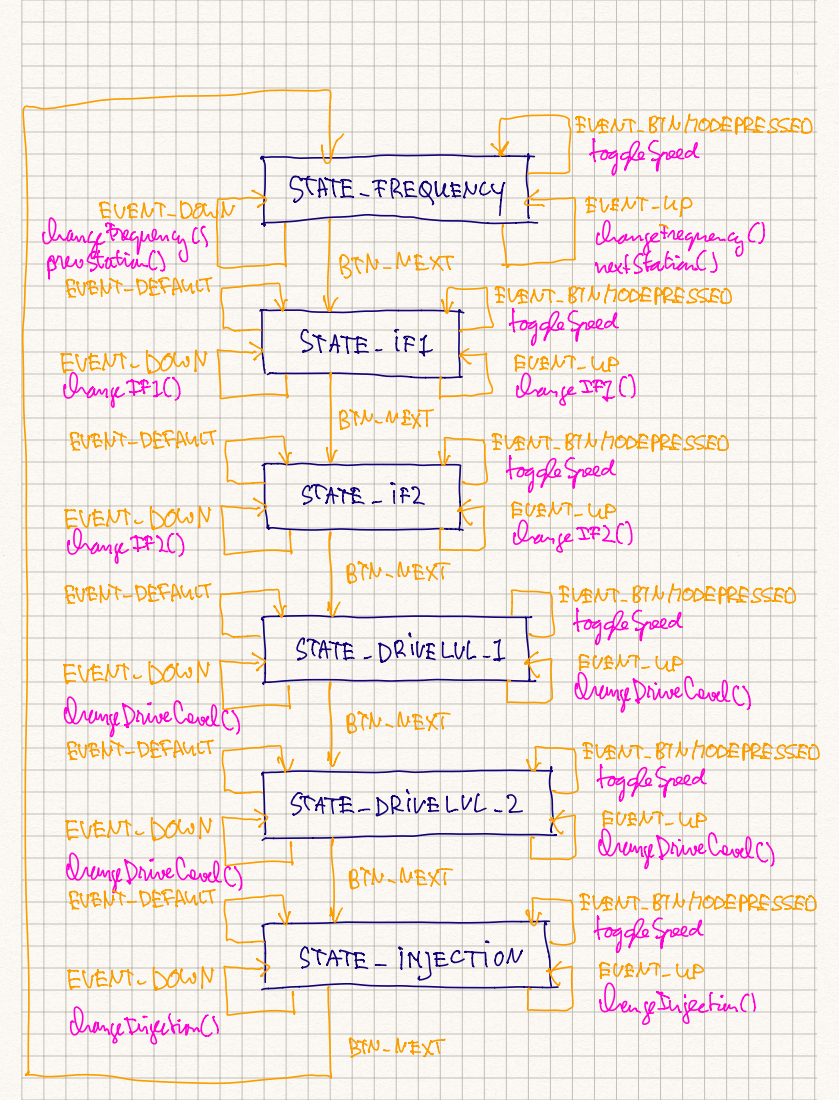
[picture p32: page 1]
Orange; langeIII

IDEËEL | PRESSED

STATE FREQUENCY

EVENTDEFA4tT

EVENT.BTb | MODEPRESSED

toggleSpeed-STATE.ir EVENTuD0WN JEUENT ⁴P
fierier

toggleSpeed-EuemDowN
drangebrivelarla JfI.IIIID | | | | | | | ÉÉN

EVENTDEFAULT | | | | | | EVENT BINNODEPRESSED
C | STATE DRIVEVL | BINNEXT | 2 | | duingebieden drangedrivelevell EVENT UP EVENT DOWN

togglespeed

EVENTDEFAULT | | | | | Event.BTNMODEPRESSED

C | STATE | | INJECTION | EVENT UP EVENT DOWN lengetjectiend changetjectima

BINNEXT

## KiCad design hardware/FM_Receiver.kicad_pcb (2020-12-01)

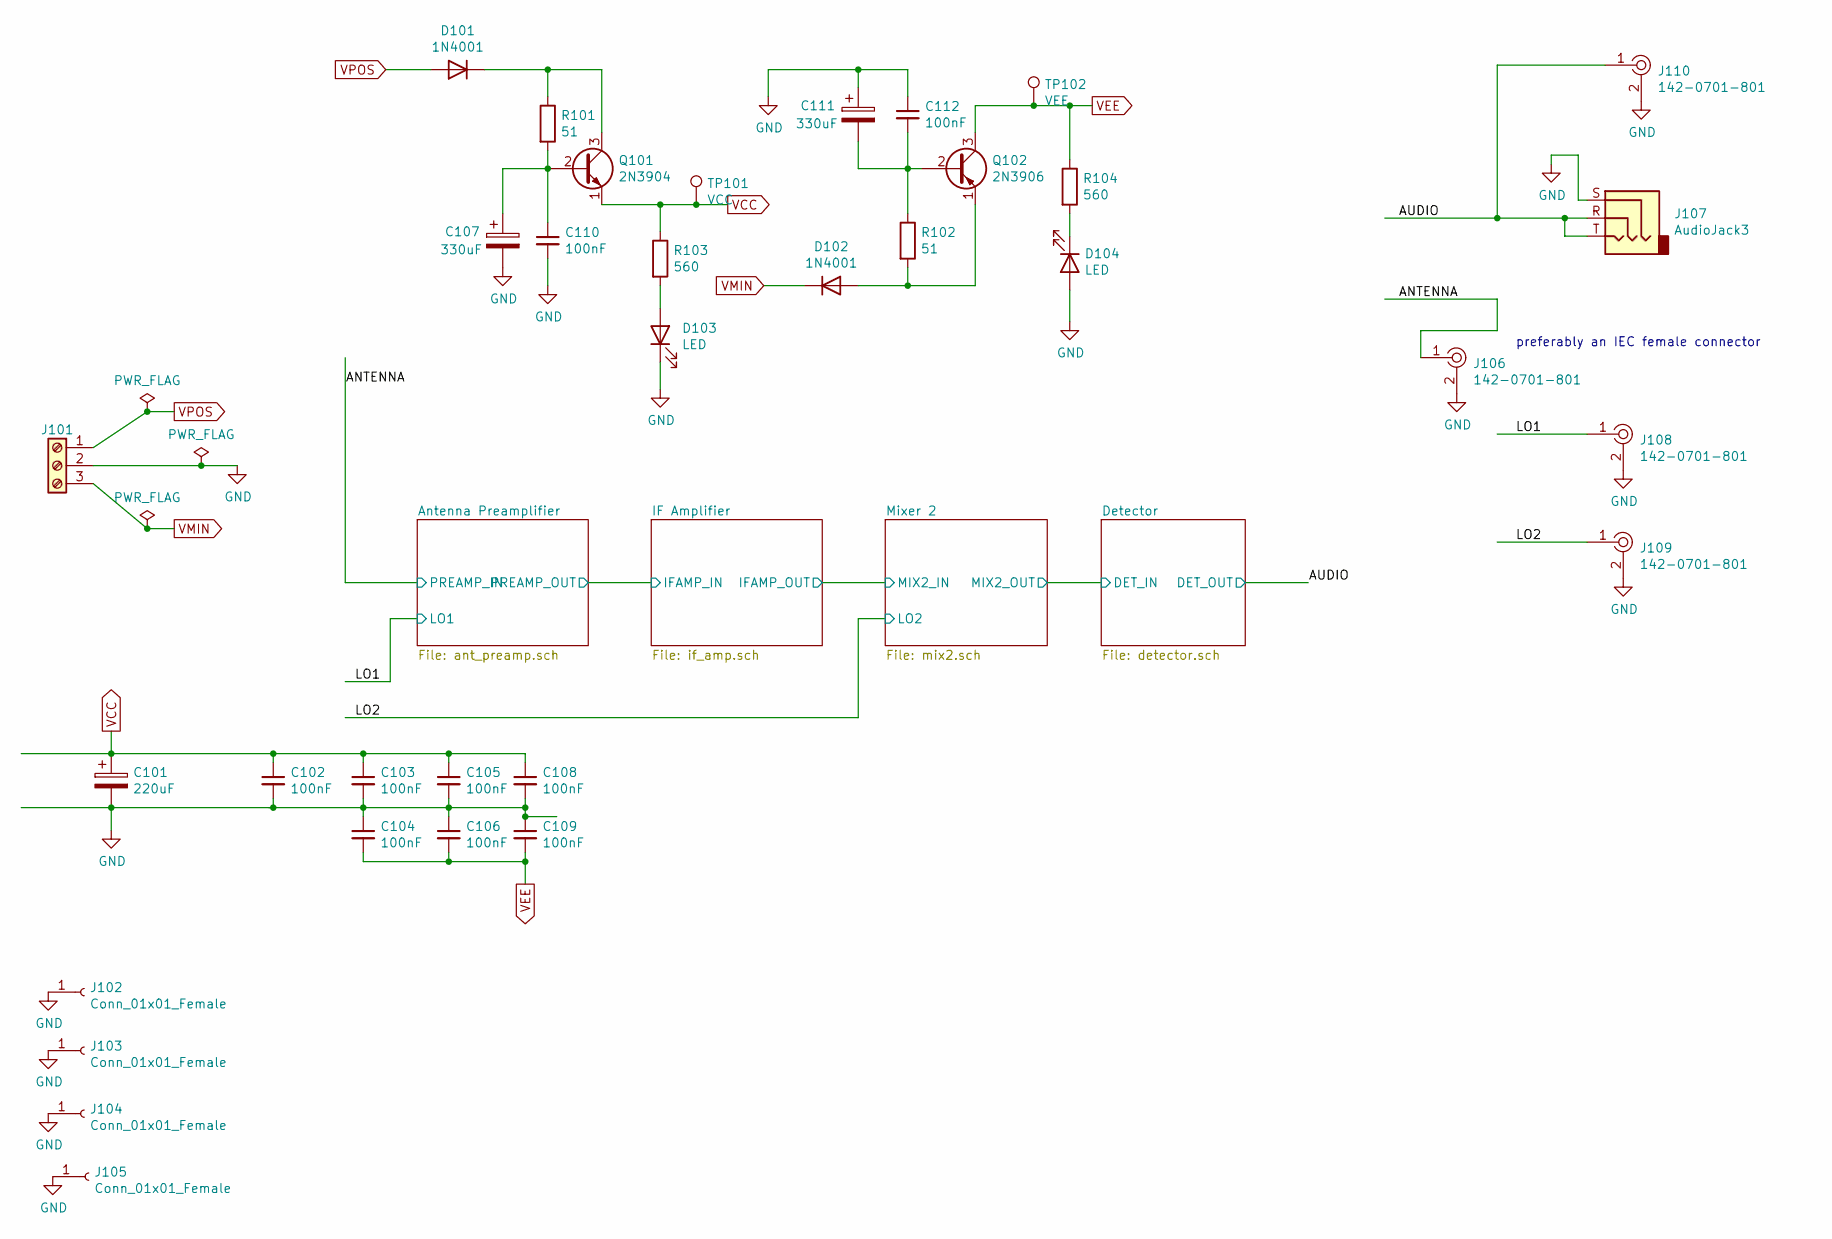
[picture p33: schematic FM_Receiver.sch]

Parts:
C101: 220uF; CP_Radial_D10.0mm_P5.00mm
C102, C103, C104, C105, C106, C108, C109, C110, C112: 100nF; C_Disc_D3.0mm_W2.0mm_P2.50mm
C107, C111: 330uF; CP_Radial_D10.0mm_P5.00mm
D101, D102: 1N4001; D_DO-41_SOD81_P7.62mm_Horizontal
D103, D104: LED; LED_D3.0mm
J101: Screw_Terminal_01x03; TerminalBlock_Phoenix_MPT-0,5-3-2.54_1x03_P2.54mm_Horizontal
J102, J103, J104, J105: Conn_01x01_Female; pad
J106, J108, J109, J110: 142-0701-801; SMA_Amphenol_901-144_Vertical; MPN 142-0701-801; Digi-Key_PN J502-ND
J107: AudioJack3; Jack_3.5mm_Ledino_KB3SPRS_Horizontal
Q101: 2N3904; TO-92_Inline
Q102: 2N3906; TO-92_Inline
R101, R102: 51; R_Axial_DIN0207_L6.3mm_D2.5mm_P10.16mm_Horizontal
R103, R104: 560; R_Axial_DIN0207_L6.3mm_D2.5mm_P10.16mm_Horizontal
TP101: VCC; TestPoint_Pad_D1.5mm
TP102: VEE; TestPoint_Pad_D1.5mm

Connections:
/ANTENNA: J106.1; also elsewhere on the board
/AUDIO: J107.R, J107.T, J110.1; also elsewhere on the board
/LO1: J108.1; also elsewhere on the board
/LO2: J109.1; also elsewhere on the board
GND: C101.2, C102.2, C103.2, C104.1, C105.2, C106.1, C107.2, C108.2, C109.1, C110.2, C111.1, C112.1, D103.1 (K), D104.2 (A), J101.2, J102.1, J103.1, J104.1, J105.1, J106.2, J107.S, J108.2, J109.2, J110.2; also elsewhere on the board
unnamed: C107.1, C110.1, Q101.2 (B), R101.2
unnamed: C111.2, C112.2, Q102.2 (B), R102.1
unnamed: D101.1 (K), Q101.3 (C), R101.1
unnamed: D102.2 (A), Q102.1 (E), R102.2
unnamed: D103.2 (A), R103.2
unnamed: D104.1 (K), R104.2
VCC: C101.1, C102.1, C103.1, C105.1, C108.1, Q101.1 (E), R103.1, TP101.1; also elsewhere on the board
VEE: C104.2, C106.2, C109.2, Q102.3 (C), R104.1, TP102.1; also elsewhere on the board
VMIN: D102.1 (K), J101.3
VPOS: D101.2 (A), J101.1

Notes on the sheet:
preferably an IEC female connector

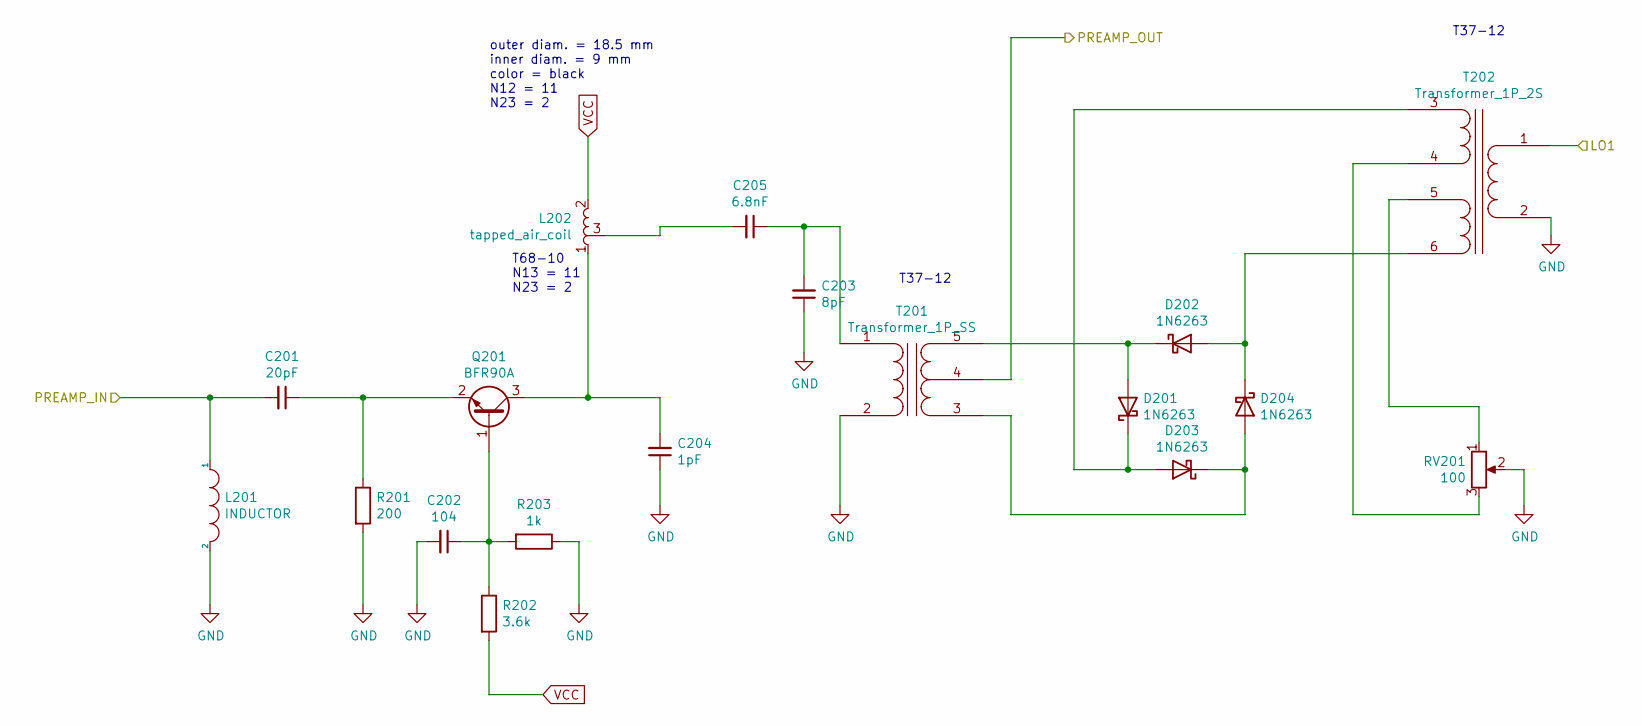
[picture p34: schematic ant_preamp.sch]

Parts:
C201: 20pF; C_Disc_D3.0mm_W2.0mm_P2.50mm
C202: 104; C_Disc_D3.0mm_W2.0mm_P2.50mm
C203: 8pF; C_Disc_D3.0mm_W2.0mm_P2.50mm
C204: 1pF; C_Disc_D3.0mm_W2.0mm_P2.50mm
C205: 6.8nF; C_Disc_D3.0mm_W2.0mm_P2.50mm
D201, D202, D203, D204: 1N6263; D_DO-35_SOD27_P7.62mm_Horizontal
L201: INDUCTOR; R_Axial_DIN0617_L17.0mm_D6.0mm_P20.32mm_Horizontal
L202: tapped_air_coil; tapped_coil
Q201: BFR90A; BFR90A_2
R201: 200; R_Axial_DIN0207_L6.3mm_D2.5mm_P10.16mm_Horizontal
R202: 3.6k; R_Axial_DIN0207_L6.3mm_D2.5mm_P10.16mm_Horizontal
R203: 1k; R_Axial_DIN0207_L6.3mm_D2.5mm_P10.16mm_Horizontal
RV201: 100; Potentiometer_Bourns_3266Y_Vertical
T201: Transformer_1P_SS; toroid_5_12
T202: Transformer_1P_2S; toroid_6_12

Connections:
/ANTENNA: C201.2, L201.1; also elsewhere on the board
/IF Amplifier/IFAMP_IN: T201.4 (SC); also elsewhere on the board
/LO1: T202.1 (AA); also elsewhere on the board
GND: C202.2, C203.1, C204.1, L201.2, R201.2, R203.1, RV201.2, T201.2 (AB), T202.2 (AB); also elsewhere on the board
unnamed: C201.1, Q201.2 (E), R201.1
unnamed: C202.1, Q201.1 (B), R202.1, R203.2
unnamed: C203.2, C205.1, T201.1 (AA)
unnamed: C204.2, L202.1, Q201.3 (C)
unnamed: C205.2, L202.3
unnamed: D201.1 (K), D203.2 (A), T202.3 (SA)
unnamed: D201.2 (A), D202.1 (K), T201.5 (SB)
unnamed: D202.2 (A), D204.1 (K), T202.6 (SD)
unnamed: D203.1 (K), D204.2 (A), T201.3 (SA)
unnamed: RV201.1, T202.5 (SC)
unnamed: RV201.3, T202.4 (SB)
VCC: L202.2, R202.2; also elsewhere on the board

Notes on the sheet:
outer diam. = 18.5 mm inner diam. = 9 mm color = black N12 = 11 N23 = 2
T37-12
T68-10 N13 = 11 N23 = 2

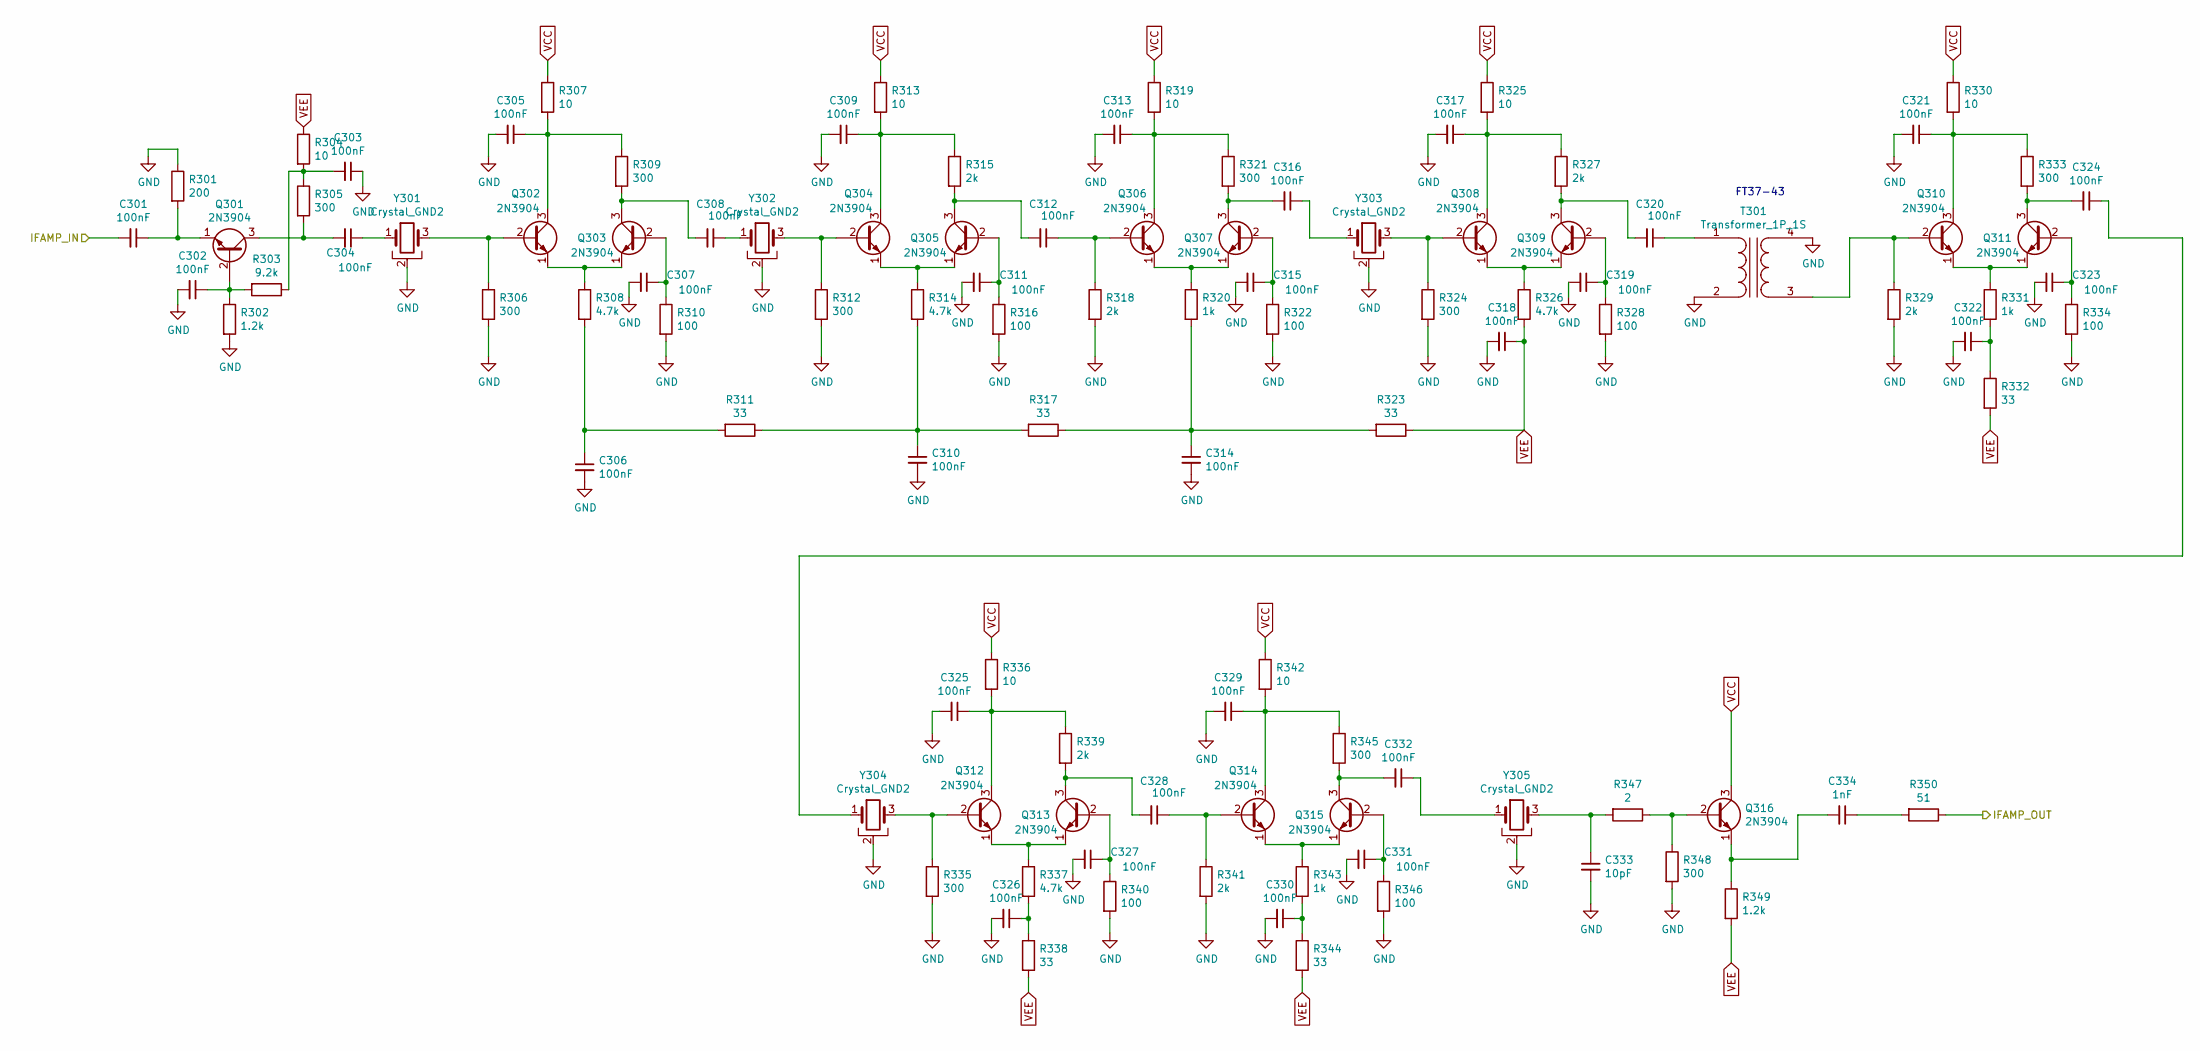
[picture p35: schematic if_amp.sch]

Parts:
C301, C302, C303, C304, C305, C306, C307, C308, C309, C310, C311, C312, C313, C314, C315, C316, C317, C318, C319, C320, C321, C322, C323, C324, C325, C326, C327, C328, C329, C330, C331, C332: 100nF; C_Disc_D3.0mm_W2.0mm_P2.50mm
C333: 10pF; C_Disc_D3.0mm_W2.0mm_P2.50mm
C334: 1nF; C_Disc_D3.0mm_W2.0mm_P2.50mm
Q301, Q302, Q303, Q304, Q305, Q306, Q307, Q308, Q309, Q310, Q311, Q312, Q313, Q314, Q315, Q316: 2N3904; TO-92_Inline
R301: 200; R_Axial_DIN0207_L6.3mm_D2.5mm_P10.16mm_Horizontal
R302, R349: 1.2k; R_Axial_DIN0207_L6.3mm_D2.5mm_P10.16mm_Horizontal
R303: 9.2k; R_Axial_DIN0207_L6.3mm_D2.5mm_P10.16mm_Horizontal
R304, R307, R313, R319, R325, R330, R336, R342: 10; R_Axial_DIN0207_L6.3mm_D2.5mm_P10.16mm_Horizontal
R305, R306, R309, R312, R321, R324, R333, R335, R345, R348: 300; R_Axial_DIN0207_L6.3mm_D2.5mm_P10.16mm_Horizontal
R308, R314, R326, R337: 4.7k; R_Axial_DIN0207_L6.3mm_D2.5mm_P10.16mm_Horizontal
R310, R316, R322, R328, R334, R340, R346: 100; R_Axial_DIN0207_L6.3mm_D2.5mm_P10.16mm_Horizontal
R311, R317, R323, R332, R338, R344: 33; R_Axial_DIN0207_L6.3mm_D2.5mm_P10.16mm_Horizontal
R315, R318, R327, R329, R339, R341: 2k; R_Axial_DIN0207_L6.3mm_D2.5mm_P10.16mm_Horizontal
R320, R331, R343: 1k; R_Axial_DIN0207_L6.3mm_D2.5mm_P10.16mm_Horizontal
R347: 2; R_Axial_DIN0207_L6.3mm_D2.5mm_P10.16mm_Horizontal
R350: 51; R_Axial_DIN0207_L6.3mm_D2.5mm_P10.16mm_Horizontal
T301: Transformer_1P_1S; toroid_4_10
Y301, Y302, Y303, Y304, Y305: Crystal_GND2; Resonator_muRata_CSTLSxxxG-3Pin_W8.0mm_H3.0mm

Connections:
/IF Amplifier/IFAMP_IN: C301.2; also elsewhere on the board
/IF Amplifier/IFAMP_OUT: R350.1; also elsewhere on the board
GND: C302.2, C303.1, C305.2, C306.2, C307.2, C309.2, C310.2, C311.2, C313.2, C314.2, C315.2, C317.2, C318.2, C319.2, C321.2, C322.2, C323.2, C325.2, C326.2, C327.2, C329.2, C330.2, C331.2, C333.2, R301.1, R302.2, R306.2, R310.2, R312.2, R316.2, R318.2, R322.2, R324.2, R328.2, R329.2, R334.2, R335.2, R340.2, R341.2, R346.2, R348.2, T301.2 (AB), T301.4 (SB), Y301.2, Y302.2, Y303.2, Y304.2, Y305.2; also elsewhere on the board
unnamed: C301.1, Q301.1 (E), R301.2
unnamed: C302.1, Q301.2 (B), R302.1, R303.2
unnamed: C303.2, R303.1, R304.2, R305.1
unnamed: C304.1, Y301.1
unnamed: C304.2, Q301.3 (C), R305.2
unnamed: C305.1, Q302.3 (C), R307.2, R309.1
unnamed: C306.1, R308.2, R311.2
unnamed: C307.1, Q303.2 (B), R310.1
unnamed: C308.1, Y302.1
unnamed: C308.2, Q303.3 (C), R309.2
unnamed: C309.1, Q304.3 (C), R313.2, R315.1
unnamed: C310.1, R311.1, R314.2, R317.2
unnamed: C311.1, Q305.2 (B), R316.1
unnamed: C312.1, Q306.2 (B), R318.1
unnamed: C312.2, Q305.3 (C), R315.2
unnamed: C313.1, Q306.3 (C), R319.2, R321.1
unnamed: C314.1, R317.1, R320.2, R323.2
unnamed: C315.1, Q307.2 (B), R322.1
unnamed: C316.1, Y303.1
unnamed: C316.2, Q307.3 (C), R321.2
unnamed: C317.1, Q308.3 (C), R325.2, R327.1
unnamed: C319.1, Q309.2 (B), R328.1
unnamed: C320.1, T301.1 (AA)
unnamed: C320.2, Q309.3 (C), R327.2
unnamed: C321.1, Q310.3 (C), R330.2, R333.1
unnamed: C322.1, R331.2, R332.1
unnamed: C323.1, Q311.2 (B), R334.1
unnamed: C324.1, Y304.1
unnamed: C324.2, Q311.3 (C), R333.2
unnamed: C325.1, Q312.3 (C), R336.2, R339.1
unnamed: C326.1, R337.2, R338.1
unnamed: C327.1, Q313.2 (B), R340.1
unnamed: C328.1, Q314.2 (B), R341.1
unnamed: C328.2, Q313.3 (C), R339.2
unnamed: C329.1, Q314.3 (C), R342.2, R345.1
unnamed: C330.1, R343.2, R344.1
unnamed: C331.1, Q315.2 (B), R346.1
unnamed: C332.1, Y305.1
unnamed: C332.2, Q315.3 (C), R345.2
unnamed: C333.1, R347.2, Y305.3
unnamed: C334.1, R350.2
unnamed: C334.2, Q316.1 (E), R349.1
unnamed: Q302.1 (E), Q303.1 (E), R308.1
unnamed: Q302.2 (B), R306.1, Y301.3
unnamed: Q304.1 (E), Q305.1 (E), R314.1
unnamed: Q304.2 (B), R312.1, Y302.3
unnamed: Q306.1 (E), Q307.1 (E), R320.1
unnamed: Q308.1 (E), Q309.1 (E), R326.1
unnamed: Q308.2 (B), R324.1, Y303.3
unnamed: Q310.1 (E), Q311.1 (E), R331.1
unnamed: Q310.2 (B), R329.1, T301.3 (SA)
unnamed: Q312.1 (E), Q313.1 (E), R337.1
unnamed: Q312.2 (B), R335.1, Y304.3
unnamed: Q314.1 (E), Q315.1 (E), R343.1
unnamed: Q316.2 (B), R347.1, R348.1
VCC: Q316.3 (C), R307.1, R313.1, R319.1, R325.1, R330.1, R336.1, R342.1; also elsewhere on the board
VEE: C318.1, R304.1, R323.1, R326.2, R332.2, R338.2, R344.2, R349.2; also elsewhere on the board

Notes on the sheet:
FT37-43

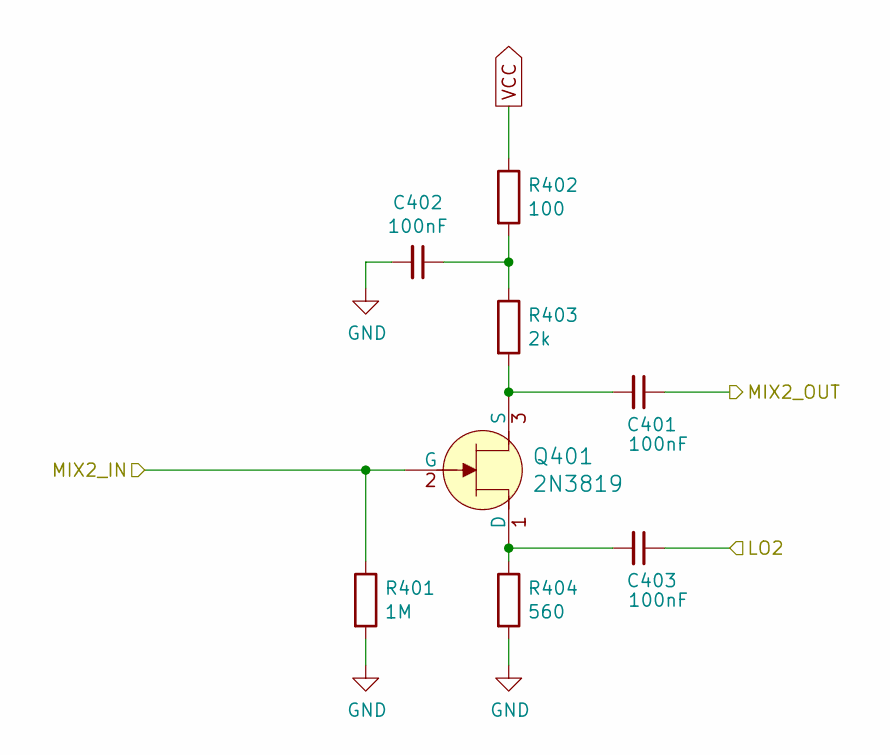
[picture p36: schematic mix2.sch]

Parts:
C401, C402, C403: 100nF; C_Disc_D3.0mm_W2.0mm_P2.50mm
Q401: 2N3819; TO-92-3; MPN 2N3819; Digi-Key_PN 2N3819CS-ND
R401: 1M; R_Axial_DIN0207_L6.3mm_D2.5mm_P10.16mm_Horizontal
R402: 100; R_Axial_DIN0207_L6.3mm_D2.5mm_P10.16mm_Horizontal
R403: 2k; R_Axial_DIN0207_L6.3mm_D2.5mm_P10.16mm_Horizontal
R404: 560; R_Axial_DIN0207_L6.3mm_D2.5mm_P10.16mm_Horizontal

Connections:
/Detector/DET_IN: C401.1; also elsewhere on the board
/IF Amplifier/IFAMP_OUT: Q401.2 (G), R401.1; also elsewhere on the board
/LO2: C403.1; also elsewhere on the board
GND: C402.2, R401.2, R404.2; also elsewhere on the board
unnamed: C401.2, Q401.3 (S), R403.2
unnamed: C402.1, R402.2, R403.1
unnamed: C403.2, Q401.1 (D), R404.1
VCC: R402.1; also elsewhere on the board

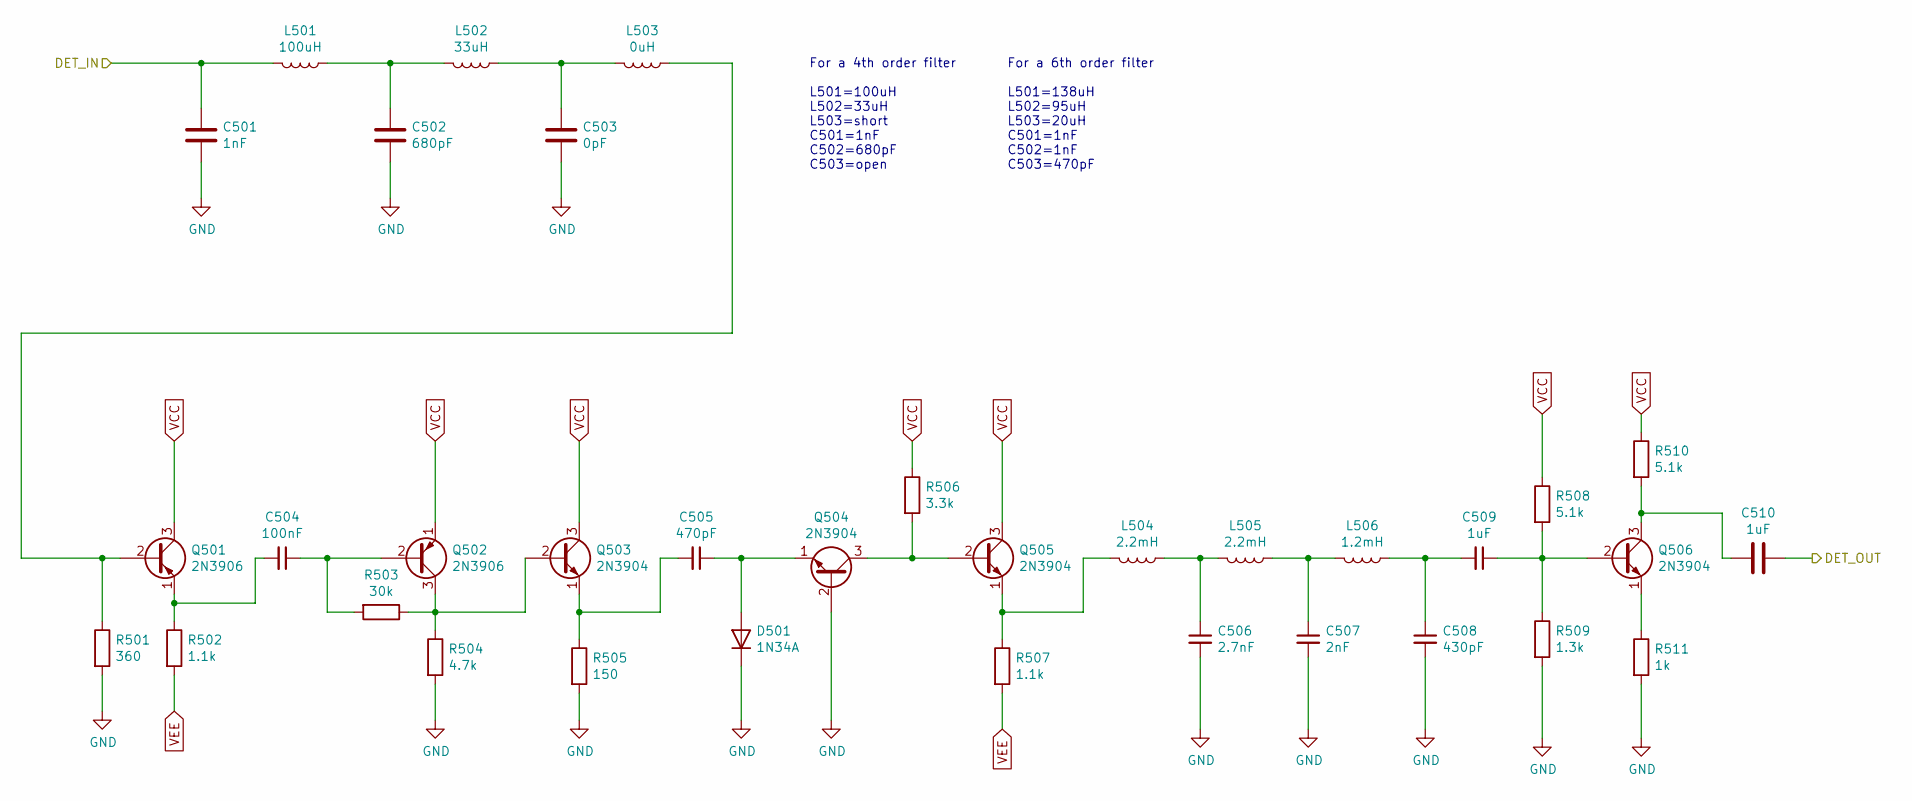
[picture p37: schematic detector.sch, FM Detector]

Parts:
C501: 1nF; C_Disc_D3.0mm_W2.0mm_P2.50mm
C502: 680pF; C_Disc_D3.0mm_W2.0mm_P2.50mm
C503: 0pF; C_Disc_D3.0mm_W2.0mm_P2.50mm
C504: 100nF; C_Disc_D3.0mm_W2.0mm_P2.50mm
C505: 470pF; C_Disc_D3.0mm_W2.0mm_P2.50mm
C506: 2.7nF; C_Disc_D3.0mm_W2.0mm_P2.50mm
C507: 2nF; C_Disc_D3.0mm_W2.0mm_P2.50mm
C508: 430pF; C_Disc_D3.0mm_W2.0mm_P2.50mm
C509, C510: 1uF; C_Rect_L10.3mm_W5.7mm_P7.50mm_MKS4
D501: 1N34A; D_DO-34_SOD68_P7.62mm_Horizontal
L501: 100uH; R_Axial_DIN0309_L9.0mm_D3.2mm_P12.70mm_Horizontal
L502: 33uH; R_Axial_DIN0309_L9.0mm_D3.2mm_P12.70mm_Horizontal
L503: 0uH; R_Axial_DIN0309_L9.0mm_D3.2mm_P12.70mm_Horizontal
L504, L505: 2.2mH; L_Radial_D8.7mm_P5.00mm_Fastron_07HCP
L506: 1.2mH; L_Radial_D8.7mm_P5.00mm_Fastron_07HCP
Q501, Q502: 2N3906; TO-92_Inline
Q503, Q504, Q505, Q506: 2N3904; TO-92_Inline
R501: 360; R_Axial_DIN0207_L6.3mm_D2.5mm_P10.16mm_Horizontal
R502, R507: 1.1k; R_Axial_DIN0207_L6.3mm_D2.5mm_P10.16mm_Horizontal
R503: 30k; R_Axial_DIN0207_L6.3mm_D2.5mm_P10.16mm_Horizontal
R504: 4.7k; R_Axial_DIN0207_L6.3mm_D2.5mm_P10.16mm_Horizontal
R505: 150; R_Axial_DIN0207_L6.3mm_D2.5mm_P10.16mm_Horizontal
R506: 3.3k; R_Axial_DIN0207_L6.3mm_D2.5mm_P10.16mm_Horizontal
R508, R510: 5.1k; R_Axial_DIN0207_L6.3mm_D2.5mm_P10.16mm_Horizontal
R509: 1.3k; R_Axial_DIN0207_L6.3mm_D2.5mm_P10.16mm_Horizontal
R511: 1k; R_Axial_DIN0207_L6.3mm_D2.5mm_P10.16mm_Horizontal

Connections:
/AUDIO: C510.1; also elsewhere on the board
/Detector/DET_IN: C501.1, L501.2; also elsewhere on the board
GND: C501.2, C502.2, C503.2, C506.2, C507.2, C508.2, D501.1 (K), Q504.2 (B), R501.2, R504.2, R505.2, R509.2, R511.2; also elsewhere on the board
unnamed: C502.1, L501.1, L502.2
unnamed: C503.1, L502.1, L503.2
unnamed: C504.1, Q502.2 (B), R503.2
unnamed: C504.2, Q501.1 (E), R502.1
unnamed: C505.1, D501.2 (A), Q504.1 (E)
unnamed: C505.2, Q503.1 (E), R505.1
unnamed: C506.1, L504.1, L505.2
unnamed: C507.1, L505.1, L506.2
unnamed: C508.1, C509.2, L506.1
unnamed: C509.1, Q506.2 (B), R508.2, R509.1
unnamed: C510.2, Q506.3 (C), R510.2
unnamed: L503.1, Q501.2 (B), R501.1
unnamed: L504.2, Q505.1 (E), R507.1
unnamed: Q502.3 (C), Q503.2 (B), R503.1, R504.1
unnamed: Q504.3 (C), Q505.2 (B), R506.2
unnamed: Q506.1 (E), R511.1
VCC: Q501.3 (C), Q502.1 (E), Q503.3 (C), Q505.3 (C), R506.1, R508.1, R510.1; also elsewhere on the board
VEE: R502.2, R507.2; also elsewhere on the board

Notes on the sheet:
For a 4th order filter L501=100uH L502=33uH L503=short C501=1nF C502=680pF C503=open
For a 6th order filter L501=138uH L502=95uH L503=20uH C501=1nF C502=1nF C503=470pF

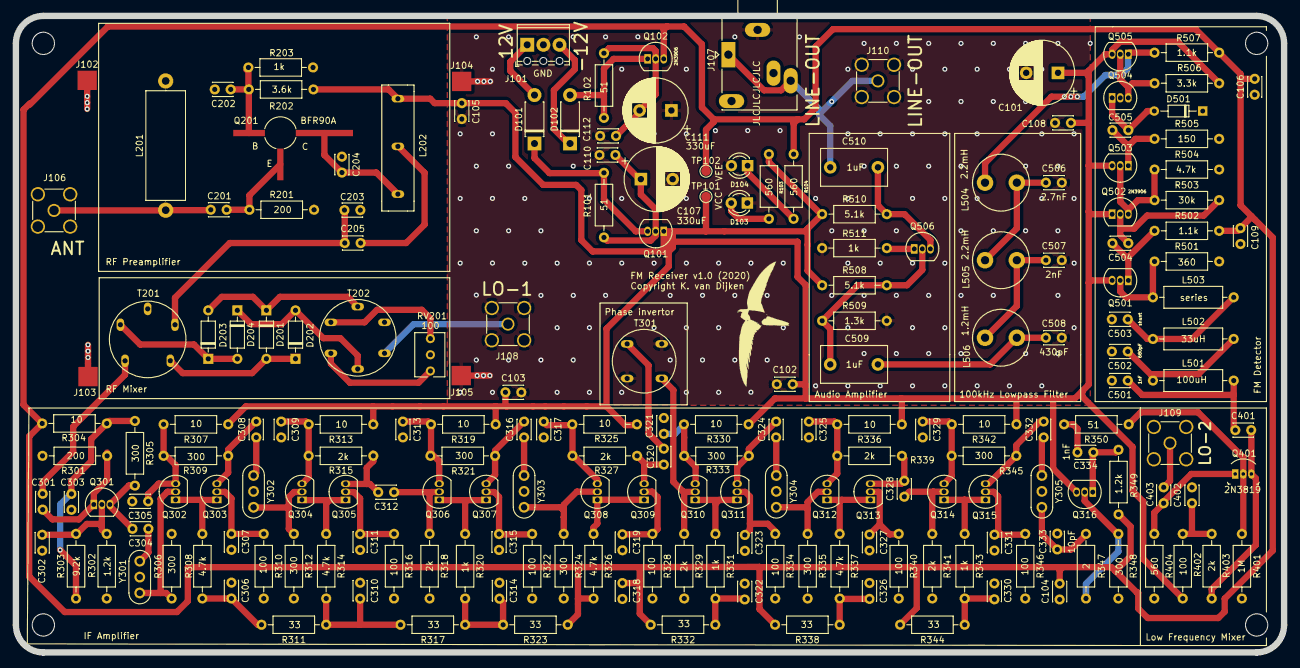
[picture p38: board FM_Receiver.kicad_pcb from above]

Board: 2 copper layers, 199.4 x 100.1 mm, 200 parts (0 on the bottom side), 103 nets.

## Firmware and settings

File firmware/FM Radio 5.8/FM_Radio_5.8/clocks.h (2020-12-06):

#ifndef CLOCKS_H
#define CLOCKS_H

// clock identifiers
#define CLK_IF1 0
#define CLK_IF2 1

// drive level for the mixers.
#define NUM_DRIVE_LEVELS 5
#define MIN_DRIVELEVEL 0
#define MAX_DRIVELEVEL NUM_DRIVE_LEVELS-1
#define RADIX_DRIVELEVEL 1

// available drive levels
#define DRIVE_LEVEL_0MA 0
#define DRIVE_LEVEL_2MA 1
#define DRIVE_LEVEL_4MA 2
#define DRIVE_LEVEL_6MA 3
#define DRIVE_LEVEL_8MA 4

// default drive levels
#define DEFAULT_DRIVELEVEL_MIXER1 DRIVE_LEVEL_4MA
#define DEFAULT_DRIVELEVEL_MIXER2 DRIVE_LEVEL_2MA

#endif

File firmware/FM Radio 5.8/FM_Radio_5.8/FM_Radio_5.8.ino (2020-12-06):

/**
   Runs a Si5351, displays KHZ's on a 8 digit MAX7221/7219 led display.
   Frequency is set using a rotary encode.

   The Si5351 runs on I2c, which uses signals SDA and SCL. It uses the
   Wire library.

   Arduino Uno: SDA is on A4, SCL is on A5
   Arduino Nano:  SDA is on A4, SCL is on A5
*/

// Define DEBUG to send text over serial port.
// #define debug 1

long FWVersion = 58;  // i.e. "5.0"
// date Dec 4, 2020

// In case of an error, stop doing anything. The program loop will be suspended.
bool dontDoAnything = false;


// ==========================================================================
// WHEN STARTING CODING ON A NEW VERSION, FIRST CREATE A NEW ARDUINO PROJECT!
// ==========================================================================

// TODO 6.0 save settings in EEPROM, using EEPROM library.
//          See https://forum.arduino.cc/index.php?topic=45204.0
// TODO 6.0 Implement a way to reset after an error has ocurred
//          https://www.theengineeringprojects.com/2015/11/reset-arduino-programmatically.html
//          Create a new state STATE_ERROR, from which we can leave
//          by pressing DEFAULT button.
// TODO 6.0 implement a fast escape from settings to frequency/station modus
// TODO 6.0 Check if granularity in error detection is still good enough
//          now stateBase() is used.
// TODO 6.0 When in stateBase() an unknown state is encountered still
//          raise an error?
// TODO 6.0 implement left button + rotary function for stepping
//          thru settings. This is getting more important when
//          we add more settings. This prevents
//          us to use the left button many times in succession.
//          This may mean two new events have to be defined:
//          SHIFT_UP and SHIFT_DOWN, where SHIFT_UP is the
//          same as NEXT

// version 5.8
// x update state machine documentation
// x Check order of preprogrammed stations, should be ascending
// x Check for any double preprogrammed stations

// version 5.7
// x remove all stateToXXX() functions. These are only routing through
//          to the stateXXX() functions.
// x many state functions have exactly the same code, only
//          differ in small details. Investigate some inherit mechanism.
//          Seems to work fine in current implementation, but is it worth it?
// x redefine EVENT_UP as EVENT_UP, similar CCW -> DOWN
// x redefine STATE_CHANGE events as EVENT
// x is EVENT_IDLE a STATE or is it an EVENT? -> an EVENT
// x L1 > 0 > default > up --> 2
// x L2 > 0 > default > up --> 2

// version 5.6
// x implement low/high side injection switching
// x implement separate drive level for IF1 and IF2
// x implement drive level = 0 for IF1 and IF2
// x improve performance for rotating rotary button
// x implement full error/result checking, display E when an error has been detected
// x rename BTN_MODE, BTN_NEXT & BTN_DEFAULT, and associated other variables and functions
// x implement UP/DOWN for rotary changes instead  of 1 and -1. Also
//   implement error checking in rotary change functions.

// version 5.5
// x document displayDigit() - what signifies 'digit' exactly
// x display IF1 as 10.70, just as the tuning freq
// x for preprogrammed stations, display "P1." etc for 2 seconds

// version 5.4
// x use SI5351 for LO2
// x change default frequency selection to fast station search
// x add RegioFM at 95.30 MHz
// x change default IF to 10.7MHz
// x change frequency radix from 0.1MHz to 0.05MHz
//   for this we also need to change the frequency display

// x fast station switching using rotation instead of button.
//   set modus using button, then change station using rotation
// x rename debouncerNext to debouncerMode
// x rename btnNext to btnMode
// x rename old_btnNext to old_btnMode
// x EVENT_BTN_MODE_PRESSED to EVENT_BTN_MODE_PRESSED
// x EVENT_BTN_MODE_RELEASED to EVENT_BTN_MODE_RELEASED
// - stateStation needs to be reprogrammed using a speedMode toggle switch
//   to change stations fast or slow
// x change changeStation() to take speedMode into account
// x remove STATE_STATION
// x remove stateStation
// - implement a LED to show slow/fast station selection => now implemented by
//   the LED which was first used for the IF settings. It was a little bit overloaded,
//   and will be more overloaded if we also implement LO drive level setting.
// x rename LED_ID to LED_FAST

// version 5.3
// x check station frequencies (102.2 -> 102.0)
// x disable serial debug info for speed
// x new state to set LO output power
// x extend range of IF2 and change default. It seems that with higher IF2
//    there is less noise

// Version 5.2 will be an attempt to use the AD9851 for LO2
// implement mixer drive, toggle using an extra button, display current drive on screen

// version 5.1
// x displayIF1, displayIF2: display "IF1" and "IF2"



/*
      The current way the state machine is implemented has been to
      generate signals at the changes of button states. When there
      has not been a change in button state, an EVENT_IDLE is generated.

      Another way to do it is as follows. Continuously generate signals
      with the current state of the buttons, and have the state function
      decide if they want to do anything with it. This will give us the
      opportunity to respond to double button presses. So the state
      functions do not register state changes, but just record current
      state, and respond to it (or not).

      This will clearly be for a new FW version.
*/

// define for use with SI5351
#define _SI5351

#include <stdio.h>
#include <stdlib.h>
#include <string.h>
#include <LedControl.h>
#include "si5351.h"
#include <Encoder.h>
#include <Bounce2.h>
#include "err.h"
#include "pins.h"
#include "states.h"
#include "stations.h"
#include "frequencies.h"
#include "clocks.h"

// How long will we stay in any of the  settings states (in miliseconds)
#define SETTINGS_SHOW_TIME 15000

// How long will we display the pre-programmed station number
// when fast selecting stations (in miliseconds).
#define STATION_SHOW_TIME 2000


// Arduino Pin 7 to DIN, 6 to Clk, 5 to LOAD, no.of devices is 1

// LedControl uses SPI, can use any of the pins
// SPI requires a separate slave select pin for any slave

LedControl lc = LedControl( LED_DATA, LED_CLK, LED_SELECT, 1 );


//Bounce bouncerRadix = Bounce( PIN_ENCODER_BTN, 50 );
Encoder encoder( PIN_ENCODER_A, PIN_ENCODER_B );


Bounce debouncerMode = Bounce();
Bounce debouncerNext = Bounce();
Bounce debouncerDefault = Bounce();

// Si5351 pieces
Si5351 si5351;



#define UP 1
#define DOWN -1

// Initial state of the state machine
int state = STATE_FREQUENCY;

#define STARTING_CRYSTAL_CAPACITANCE SI5351_CRYSTAL_LOAD_8PF
//#define STARTING_FREQ_CORRECTION -5700
#define STARTING_FREQ_CORRECTION 10720

// Radix for frequency dialing (in Hz)
long radix = 10000;

long frequency = INITIAL_FREQUENCY;  // in Hz

// intermediate frequency
long iFreq1 = DEFAULT_IF1;   // in Hz
long iFreq2 = DEFAULT_IF2;   // in Hz

long radixIF1 = 10000; // = 10KHZ
long radixIF2 = 10000; // = 10KHZ

// Drive levels for the local oscillators
int driveLevels[NUM_DRIVE_LEVELS] = { DRIVE_LEVEL_0MA,
                                      DRIVE_LEVEL_2MA,
                                      DRIVE_LEVEL_4MA,
                                      DRIVE_LEVEL_6MA,
                                      DRIVE_LEVEL_8MA };
int driveLevelsDisplay[NUM_DRIVE_LEVELS] = { 0, 2, 4, 6, 8 }; // What to display
int driveLevel[2] = { DEFAULT_DRIVELEVEL_MIXER1, DEFAULT_DRIVELEVEL_MIXER2 };        // index into driveLevels[] and driveLevelsDisplay[]

// Frequency selection
// SLOW = let user select exact frequency
// FAST = let user select preprogrammed stations
#define SPEED_MODE_SLOW 0
#define SPEED_MODE_FAST 1
#define DEFAULT_SPEED_MODE SPEED_MODE_FAST
int speedMode = DEFAULT_SPEED_MODE;



/**
  Displays a digit at location 'digit'. Location '0' is the rightmost
  digit. If decimalPoint == true, a decimal point will be displayed
  after the displayed digit. Parameter 'r' determines the digit to
  be displayed;
  r = 0: '0'
  r = 1: '1'
  r = 2: '2'
  r = 3: '3'
  r = 4: '4'
  r = 5: '5'
  r = 6: '6'
  r = 7: '7'
  r = 8: '8'
  r = 9: '9'
  r = 10: ' '
  r = 11: 'A'
  r = 12: 'b'
  r = 13: 'C'
  r = 14: 'd'
  r = 15: 'E'
  r = 16: 'F'
  r = 17: 'h'
  r = 18: 'L'
  r = 19: 'P'
  r = 20: '_'

*/
#define CHAR_0 0
#define CHAR_1 1
#define CHAR_2 2
#define CHAR_3 3
#define CHAR_4 4
#define CHAR_5 5
#define CHAR_6 6
#define CHAR_7 7
#define CHAR_8 8
#define CHAR_9 9
#define CHAR_SPACE 10
#define CHAR_A 11
#define CHAR_B 12
#define CHAR_C 13
#define CHAR_D 14
#define CHAR_E 15
#define CHAR_F 16
#define CHAR_H 17
#define CHAR_L 18
#define CHAR_P 19
#define CHAR__ 20

char c[21] = { '0', '1', '2', '3', '4', '5', '6', '7', '8', '9', ' ', 'A', 'b', 'C', 'd', 'E', 'F', 'h', 'L', 'P', '_'  };
bool displayDigit( int digit, byte r, bool decimalPoint ) {
  bool result = true;
  lc.setChar( 0, digit, c[r], decimalPoint );
  return result;
}


#define HISIDE 1
#define LOWSIDE 2
#define DEFAULT_INJECTION LOWSIDE

int injection = DEFAULT_INJECTION;

bool displayInjection() {
  bool result = true;
  // Display HiLo
  lc.setRow( 0, 7, B00110111 );  // H
  lc.setRow( 0, 6, B00001110 );  // L

  // Display either hi or lo
  if( injection == HISIDE ) {
    lc.setRow( 0, 1, B00010111 );  // H
    lc.setRow( 0, 0, B00000100 );  // i
  } else if( injection == LOWSIDE ) {
    lc.setRow( 0, 1, B00110000 );  // L
    lc.setRow( 0, 0, B00011101 );  // o
  } else
    result = false;
  return result;
}


int err = ERR_OK;

bool displayError( int error ) {
  bool result = true;

  clearDisplay();

  // Display 'Error'
  displayDigit( 7, CHAR_E, 0 ); // E
  lc.setRow( 0, 6, 0x05 );  // r
  lc.setRow( 0, 5, 0x05 );  // r
  lc.setRow( 0, 4, 0x1D );  // o
  lc.setRow( 0, 3, 0x05 );  // r

  // Display the error number
  displayLong( error, 0, false );

  return result;
}


/**
   Displays a long.

   Parameter 'decimals' signifies the number
   of digits after the decimal point.

   Examples:
   52, 1 prints 5.2
   9750, 2 prints 97.50
   8, 1 prints 8

   If parameter wipeLeft == true all characters left
   of the displayed digits will be wiped to spaces
   (but only in the frequency pane. The info pane will
   be left intact).
*/
bool displayLong( long n, int decimals, bool wipeLeft ) {
  bool result = true;
  int i;
  // The increment statement is executed after the body
  // of the for loop structure.
  for ( i=0; i<8 && (n>0 || i==0); i++ ) {
    // Always print a digit if i==0 to print something for n==0;
    int r = n % 10;
    n /= 10;
    // We have already displayed i more digits.
    result = result && displayDigit( i, (byte)r, i == decimals );
  }

  // Fill the remaining digits left of the
  // already printed digits with spaces.
  if ( wipeLeft && n == 0 )
    for ( int j = i; j < 5; j++ )
      // (byte) 10 is a space
      result = result && displayDigit( j, (byte) 10, false );
  return result;
}


/**
   displayFrequency

   Displays the frequency as xx.xx MHz

   frequency (in Hz)
*/
bool displayFrequency()
{
  bool result = true;
  
#ifdef debug
  Serial.print( "displayFrequency " );
  Serial.println( frequency );
#endif

  // only display the 10KHZ part of frequency
  long f = frequency / 10000;
  result = result && displayLong( f, 2, true );
  return result;
}


/**
 * 
*/
bool displayFWVersion() {
  bool result = true;
  result = result && displayLong( FWVersion, 1, true );
  return result;
}


/**
 * 
*/
bool displayIF1()
{
  bool result = true;

  // display the KHZ part of first intermediate frequency
  long f = iFreq1 / 1000;
  result = result && displayLong( f, 3, true );

  // Display which IF we are showing.
  result = result && displayDigit( 7, CHAR_F, false );
  result = result && displayDigit( 6, CHAR_1, false );

  return result;
}


/**
 * 
*/
bool displayIF2()
{
  bool result = true;

  long f = iFreq2 / 1000;

  // Now the frequency is in KHZ
  // Intermediate frequency 2 is always less then 1000 KHZ.
  // We show the KHZ part...
  result = result && displayLong( f, -1, true );

  // ... and also the MHz part (which is 0).
  result = result && displayDigit( 3, CHAR_0, true );

  // Display which IF we are showing.
  result = result && displayDigit( 7, CHAR_F, false );
  result = result && displayDigit( 6, CHAR_2, false );
  return result;
}


/**
   Displays the drive level for the given clock.
   This assumes that the memory variable for the
   LO drive level has been set correctly.

   clock = CLK_IF1 or CLK_IF2
*/
bool displayDriveLevel( int clock )
{
  bool result = true;

  // At the left side of the display we show what LO
  // we are showing the drive level of.
  result = result && displayDigit( 7, CHAR_L, false );
  switch( clock ) {
    case CLK_IF1:
      result = result && displayDigit( 6, CHAR_1, false );
      break;
    case CLK_IF2:
      result = result && displayDigit( 6, CHAR_2, false );
      break;
    default:
      err = ERR_ILLEGAL_CLOCK;
      result = false;
      break;
  }

  // At the right side of the display we show the drive level
  result = result && displayLong( driveLevelsDisplay[driveLevel[clock]], -1, true );

  return result;
}


/**
   This programs the first oscillator for IF1.
   This is dependent on the tuning frequency and the required
   first intermediate frequency.

   It sets the frequency for the first mixer LO. The first mixer should mix
   a signal at the frequency the radio is tuned to down to IF1. So the frequency
   of the LO of the first mixer should be at 'frequency' - LO1.
*/
bool setOSC1() {
  bool result = true;
  uint64_t freqLO1;
  switch( injection ) {
    case LOWSIDE:
      freqLO1 = frequency + FREQUENCY_CORRECTION - iFreq1;
      break;
    case HISIDE:
      freqLO1 = frequency + FREQUENCY_CORRECTION + iFreq1;
      break;
    default:
      err = ERR_ILLEGAL_INJECTION;
      result = false;
  }
#ifdef debug
  Serial.println();
  Serial.println( "setOSC1()" );
  Serial.print( "freqLO1 = " );
  Serial.println( (unsigned long) freqLO1 );
#endif
  if( result )
    si5351.set_freq( freqLO1 * 100ULL, SI5351_CLK0 );

  // Now also the frequency for the second mixer LO needs to be reset again
  // The second LO depends on the IF1 and IF2.
  result = result && setOSC2();

  return result;
}


/**
   This programs the second oscillator for IF2.

   It sets the frequency for the second mixer LO. The second mixer should mix
   a signal at IF1 down to IF2. So the LO should be tuned to IF1 - IF2.
*/
bool setOSC2() {
  bool result = true;
  uint64_t freqLO2 = iFreq1 - iFreq2;
#ifdef debug
  Serial.println();
  Serial.println( "setOSC2()" );
  Serial.print( "freqLO2 = " );
  Serial.println( (unsigned long) freqLO2 );
#endif
  //  dds.setFrequency( freqLO2 );
  si5351.set_freq( freqLO2 * 100ULL, SI5351_CLK1 ); // d = 0 KHZ
  return result;
}


/*
   Use this function if a new frequency has been set and needs to be used.

   It displays the frequency and sets the local oscillator(s).

*/
bool newFrequency() {
  bool result = true;
  result = result && displayFrequency();
  
#ifdef debug
  Serial.println();
  Serial.println( "newFrequency()" );
  Serial.print( "frequency = " );
  Serial.println( frequency );
#endif

  // Radio is tuned by setting the first oscillator.
  result = result && setOSC1();
  return result;
}


/*
   Change the frequency the radio is tuned to.

   dir == 1:  increment by radix
   dir == -1: decrement by radix
*/
bool changeFrequency( short dir )
{
  bool result = true;
  switch( dir ) {
    case UP:
      frequency += radix;
      if (frequency > MAX_FREQUENCY)
        frequency = MAX_FREQUENCY;
      break;
    case DOWN:
      if ( frequency > MIN_FREQUENCY + radix )
        frequency -= radix;
      else
        frequency = MIN_FREQUENCY;
      break;
    default:
      result = false;
  }
  result = result && newFrequency();
  return result;
}


bool displayingStation = false;

/*
   Displays the station number as ' 1.' or '12.'
   Sets a timer. After a certain (preprogrammed) time,
   the station number will disappear again.
*/
bool displayStation( int i ) {
  bool result = true;

  // in any case we will have to update the station number.
  if ( i < 10 ) {
    // One digit
    result = result && displayDigit( 7, CHAR_SPACE, false );
    result = result && displayDigit( 6, i, true );
  } else {
    // Two digits
    result = result && displayDigit( 7, i / 10, false );
    result = result && displayDigit( 6, i % 10, true );
  }

  displayingStation = true;
  result = result && startStationTimer();

  return result;
}


/**
   Empties the info pane.
   The info pane are the two leftmost
   characters in the display.
*/
bool emptyInfoPane() {
  bool result = true;
  result = result && displayDigit( 7, CHAR_SPACE, false );
  result = result && displayDigit( 6, CHAR_SPACE, false );
  return result;
}


/**
   Clears the entire display.
*/
bool clearDisplay() {
  bool result = true;
  for ( int i = 0; i < 8 && result; i++ )
    result = result && displayDigit( i, CHAR_SPACE, false );
  return result;
}


/*
   Cleans up the area taken up by the station indication.
   Erases the first two characters in the display.
*/
bool hideStation() {
  bool result = true;
  if ( !displayingStation ) {
    // Not displaying the station number.
    // This must be a programming error.
    err = ERR_ILLEGAL_STATION;
    result = false;
  } else {
    result = result && emptyInfoPane();
    displayingStation = false;
  }
  return result;
}


/**
   Changes frequency to the frequency of the
   previous preprogrammed station. If there is no
   previous station, go to the last station.
*/
bool prevStation()
{
  bool result = false;
  int i = NSTATIONS - 1;

  // Find the last frequency in freqs[] which is smaller than 'frequency'.
  // freqs[] unit is STATIONS_UNIT, frequency is in Hz
  for ( ; i >= 0 && !result; i-- )
    if ( freqs[i] * STATIONS_UNIT < frequency )
      result = true;
  // after the body of the loop is completed, the dec statement
  // will be executed. See https://www.tutorialspoint.com/cprogramming/c_for_loop.htm
  // So i contains the station number (zero-based) before the tested station.

  int s = i + 1; // freqs[s] is the station to be selected.
  if ( result ) {
    // freqs[i+1] * STATIONS_UNIT < frequency
    // i+1 the the first station with frequency
    // lower than the current frequency
    // freqs[s] * STATIONS_UNIT < frequency
  }

  if( !result ) {
    // wrap around, select the last station
    s = NSTATIONS - 1;
    result = true;
  }

  // i contains the station to be selected now
  frequency = freqs[s] * STATIONS_UNIT;

  result = result && newFrequency();
  result = result && displayStation( s + 1 ); // station list is zero-based

  return result;
}


/**
   Changes frequency to the frequency of the
   next preprogrammed station. If there is no
   next station, go to the first station.
*/
bool nextStation()
{
  bool result = false;
  int i = 0;

  // Find the first frequency in freqs[] which is larger than 'frequency'.
  // freqs[] unit is STATIONS_UNIT, frequency is in Hz
  for ( ; i < NSTATIONS && !result; i++ )
    if ( freqs[i] * STATIONS_UNIT > frequency )
      result = true;
  // after the body of the loop is completed, the inc statement
  // will be executed. See https://www.tutorialspoint.com/cprogramming/c_for_loop.htm
  // So i contains the station number (zero-based) after the tested station.

  int s = i - 1; // freqs[s] is the station to be selected.
  if ( result ) {
    // freqs[i-1] * STATIONS_UNIT < frequency
    // i+1 the the first station with frequency
    // lower than the current frequency
    // freqs[s] * STATIONS_UNIT < frequency
  }

  if ( !result ) {
    // wrap around, select the first station
    s = 0;
    result = true;
  }

  // i contains the station to be selected now
  frequency = freqs[s] * STATIONS_UNIT;

  result = result && newFrequency();
  result = result && displayStation( s + 1 ); // remember the list of stations is zero-based

  return result;
}


/**
 * 
*/
bool changeIF1( short dir ) {
  bool result = true;
  switch( dir ) {
    case UP:
      iFreq1 += radixIF1;
      if ( iFreq1 > MAX_IF1 )
        iFreq1 = MAX_IF1;
      break;
    case DOWN:
      if ( iFreq1 > MIN_IF1 + radixIF1 )
        iFreq1 -= radixIF1;
      else
        iFreq1 = MIN_IF1;
      break;
    default: 
      result = false;
      break;
  }
  result = result && displayIF1();
  result = result && setOSC1();
  return result;
}


/**
 * 
*/
bool changeIF2( short dir ) {
  bool result = true;
  switch( dir ) {
    case UP:
      iFreq2 += radixIF2;
      if ( iFreq2 > MAX_IF2 )
        iFreq2 = MAX_IF2;
      break;
    case DOWN:
      if ( iFreq2 > MIN_IF2 + radixIF2 )
        iFreq2 -= radixIF2;
      else
        iFreq2 = MIN_IF2;
      break;
    default: 
      result = false;
      break;
  }
  result = result && displayIF2();
  result = result && setOSC2();
  return result;
}


/**
 * 
*/
bool changeDriveLevel( int clock, short dir ) {
  bool result = true;
  switch( dir ) {
    case UP:
      driveLevel[clock] += RADIX_DRIVELEVEL;
      if ( driveLevel[clock] > MAX_DRIVELEVEL )
        driveLevel[clock] = MAX_DRIVELEVEL;
      break;
    case DOWN:
      if ( driveLevel[clock] > MIN_DRIVELEVEL + RADIX_DRIVELEVEL)
        driveLevel[clock] -= RADIX_DRIVELEVEL;
      else
        driveLevel[clock] = MIN_DRIVELEVEL;
      break;
    default:
      result = false;
      break;
  }
  result = result && displayDriveLevel( clock );
  result = result && setSi5351DriveLevel( clock );
  return result;
}


/**
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
void loop() {
  if ( !dontDoAnything )
    doLoopBody();
}

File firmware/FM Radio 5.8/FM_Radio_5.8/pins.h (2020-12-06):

#ifndef PINS_H
#define PINS_H

// Purple labels in Arduino Nano pinout diagram.

// Pins for rotary encode

// D7
#define PIN_ENCODER_A    7

// D8
#define PIN_ENCODER_B    8



// LED Display pins

// D9
#define LED_DATA 9

// D10
#define LED_SELECT 10

// A0
#define LED_CLK 14

// IF pins

// D2
#define LED_FAST 2

// D4
#define BTN_MODE 4

// A3
#define BTN_NEXT 17

// D3
#define BTN_DEFAULT 3



// Pins for AD9851

// D11
#define SPI_DATA 11

// D13
#define SPI_CLK 13

// A1
#define AD9851_RESET_PIN  15

// A2
#define AD9851_FQ_UD_PIN  16



// Pins for Si5351

// A4
#define I2C_SDA 18

// A5
#define I2C_CLS 19



/*
   Pins in use:

   2 LED_FAST
   3 BTN_NEXT_DEFAULT
   4 BTN_MODE
   7 PIN_ENCODER_A
   8 PIN_ENCODER_B
   9 LED_DATA
   10 LED_SELECT
   11 SPI_DATA
   13 SPI_CLK
   14 LED_CLK
   15 AD9851_RESET_PIN
   16 AD9851_FQ_UD_PIN
   17 BTN_NEXT
   18 I2C_SDA
   19 I2C_CLS

   Purple labels in Arduino Nano pinout diagram.
*/

#endif

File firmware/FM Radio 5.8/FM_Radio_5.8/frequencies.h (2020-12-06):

#ifndef FREQUENCIES_H
#define FREQUENCIES_H

// Frequencies
// Lower frequency limit 87.5MHz (in Hz)
//#define MIN_FREQUENCY  87500000
#define MIN_FREQUENCY  1000000
// Upper frequency limit 108MHz (in Hz)
//#define MAX_FREQUENCY 108000000
#define MAX_FREQUENCY 220000000
// all frequencies are in 1 Hz

#define HZ 1
#define KHZ 1000
#define MHZ 1000000

// in Hz
#define INITIAL_FREQUENCY RADIONOORD * MHZ

#define MIN_IF1 10000000
#define MAX_IF1 11000000
#define DEFAULT_IF1 10660000
#define MIN_IF2 100000
#define MAX_IF2 500000
#define DEFAULT_IF2 450000

// Frequency correction which is used to set the frequency
// of the first local oscillator.
#define FREQUENCY_CORRECTION -10000

#endif

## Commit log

2020-12-06 initial commit
    initial commit
    [FM_Receiver_1.kicad_pcb, FM_Receiver_2.kicad_pcb]
2020-12-15 Initial commit
    Power Measurements

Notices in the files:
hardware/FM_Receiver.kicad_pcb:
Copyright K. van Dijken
